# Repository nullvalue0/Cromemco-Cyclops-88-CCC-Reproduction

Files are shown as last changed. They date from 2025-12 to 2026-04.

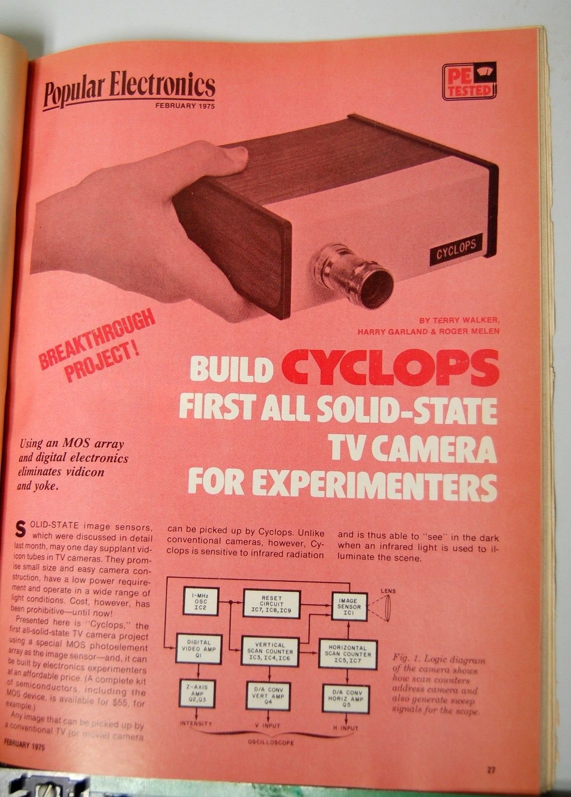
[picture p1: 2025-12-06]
Original Images/Popular Electronics Article 01.JPG

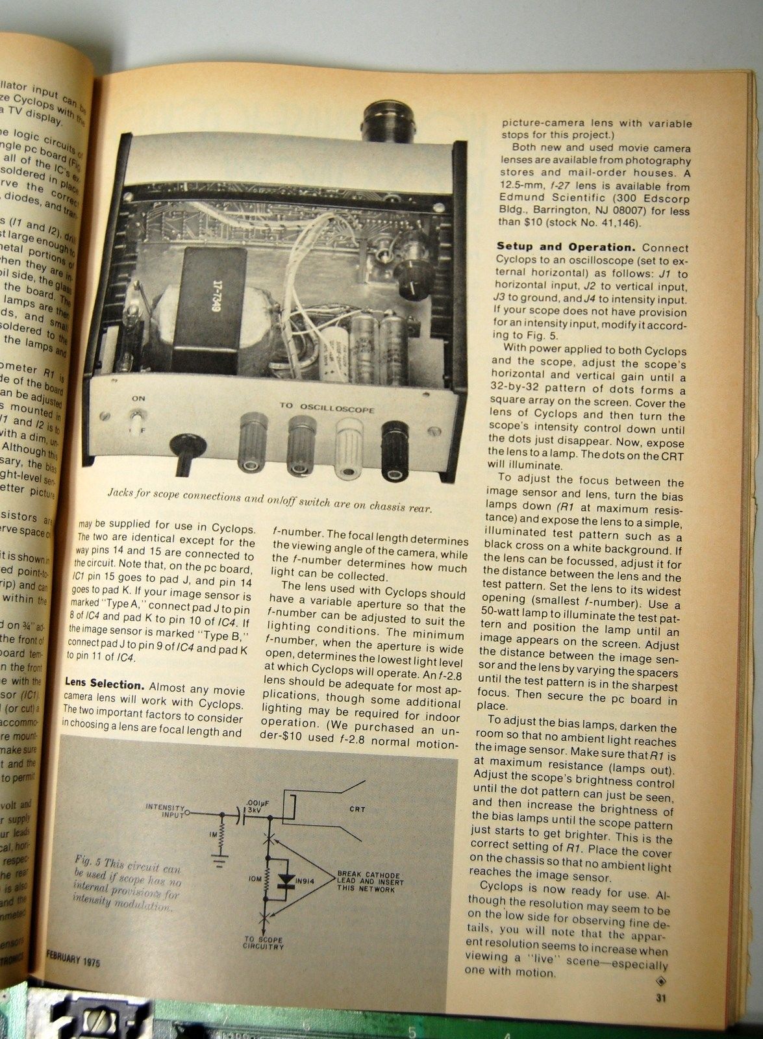
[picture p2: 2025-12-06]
Original Images/Popular Electronics Article 02.JPG

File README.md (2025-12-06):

This is an attempt to reproduce the PCB's for the Cromemco Cyclops digital camera, the 2-board set "88 CCC". The original digital cameras are basically impossible to find. Thankfully there has already been a [reproduction effort for the camera itself](http://wsudbrink.dyndns.org:8080/cyclops/index.html).

The next missing piece then would be the controller boards. While a few of the 88 CCC's have turned up, they are mainly already in collectors hands and still very rare. In several years of trying to find them I haven't been able to nab a set.

With the [Dazzler boards already successfully reproduced](https://forum.vcfed.org/index.php?threads/cromemco-dazzler-replica-project.77906), this seems like a great next project. I'll update this readme as the project progresses.

The 'Original Images' folder contains pictures of the original board set that I've found on various sites.

The 'Original Schematics' folder contains the original manual & schematics for the 88 CCC. I've combined the 2-page schematic into a single image for each board, making it much easier to reference.

The PCB folder will contain the reproduction Kicad files & gerbers for both S-100 boards.

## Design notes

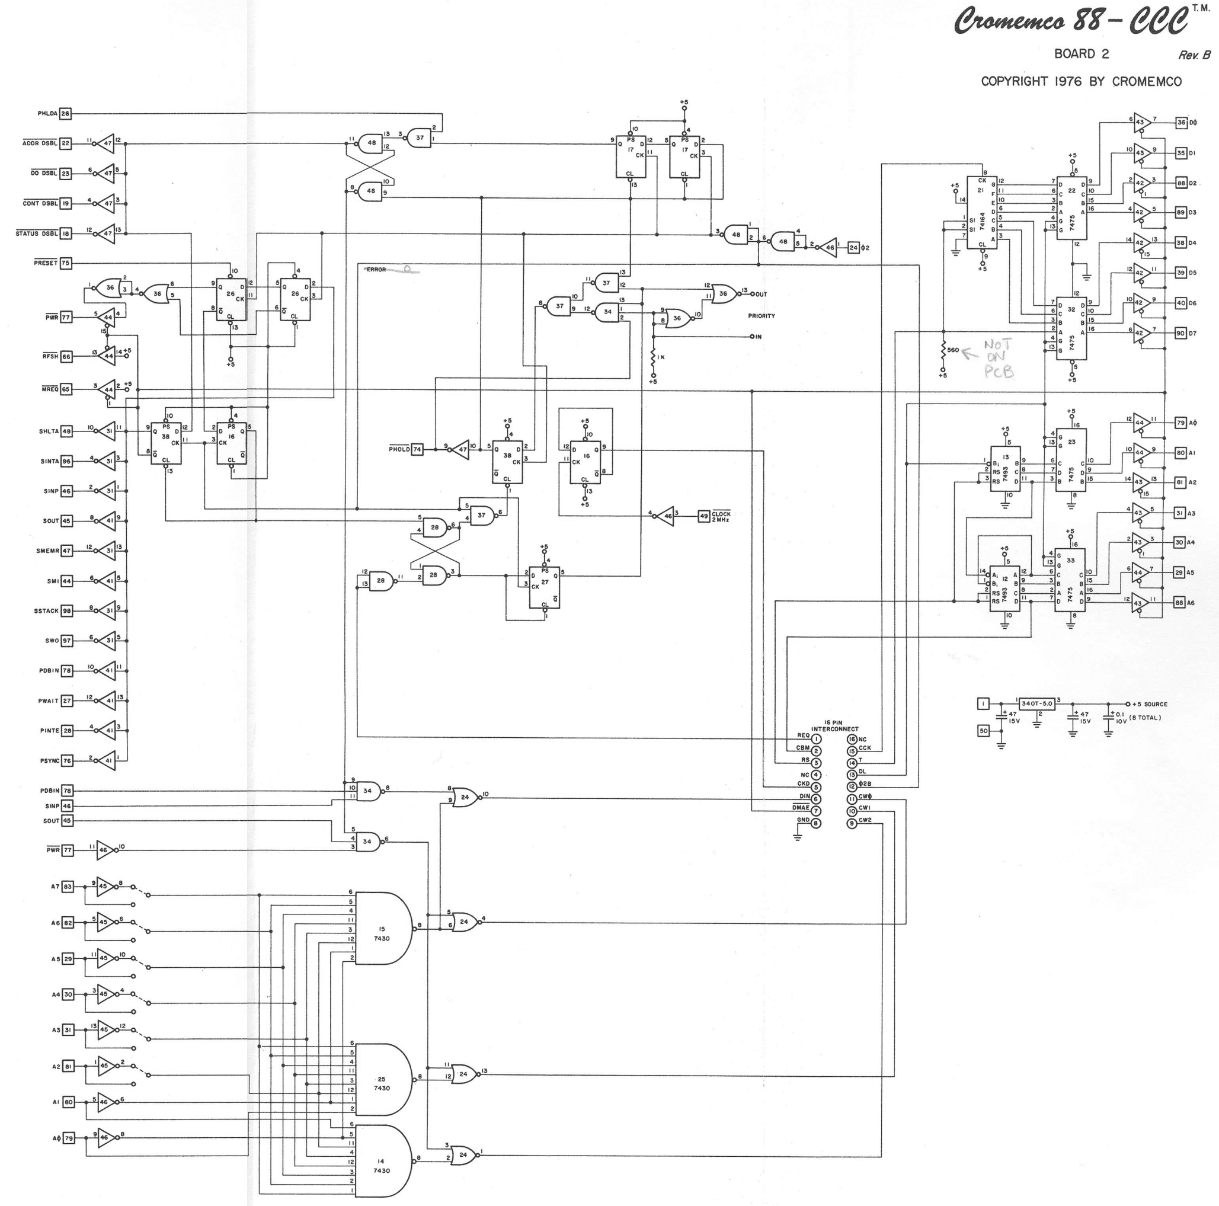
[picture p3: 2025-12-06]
Original Schematics/Cromemco_88-CCC_schematic-Board-2.png

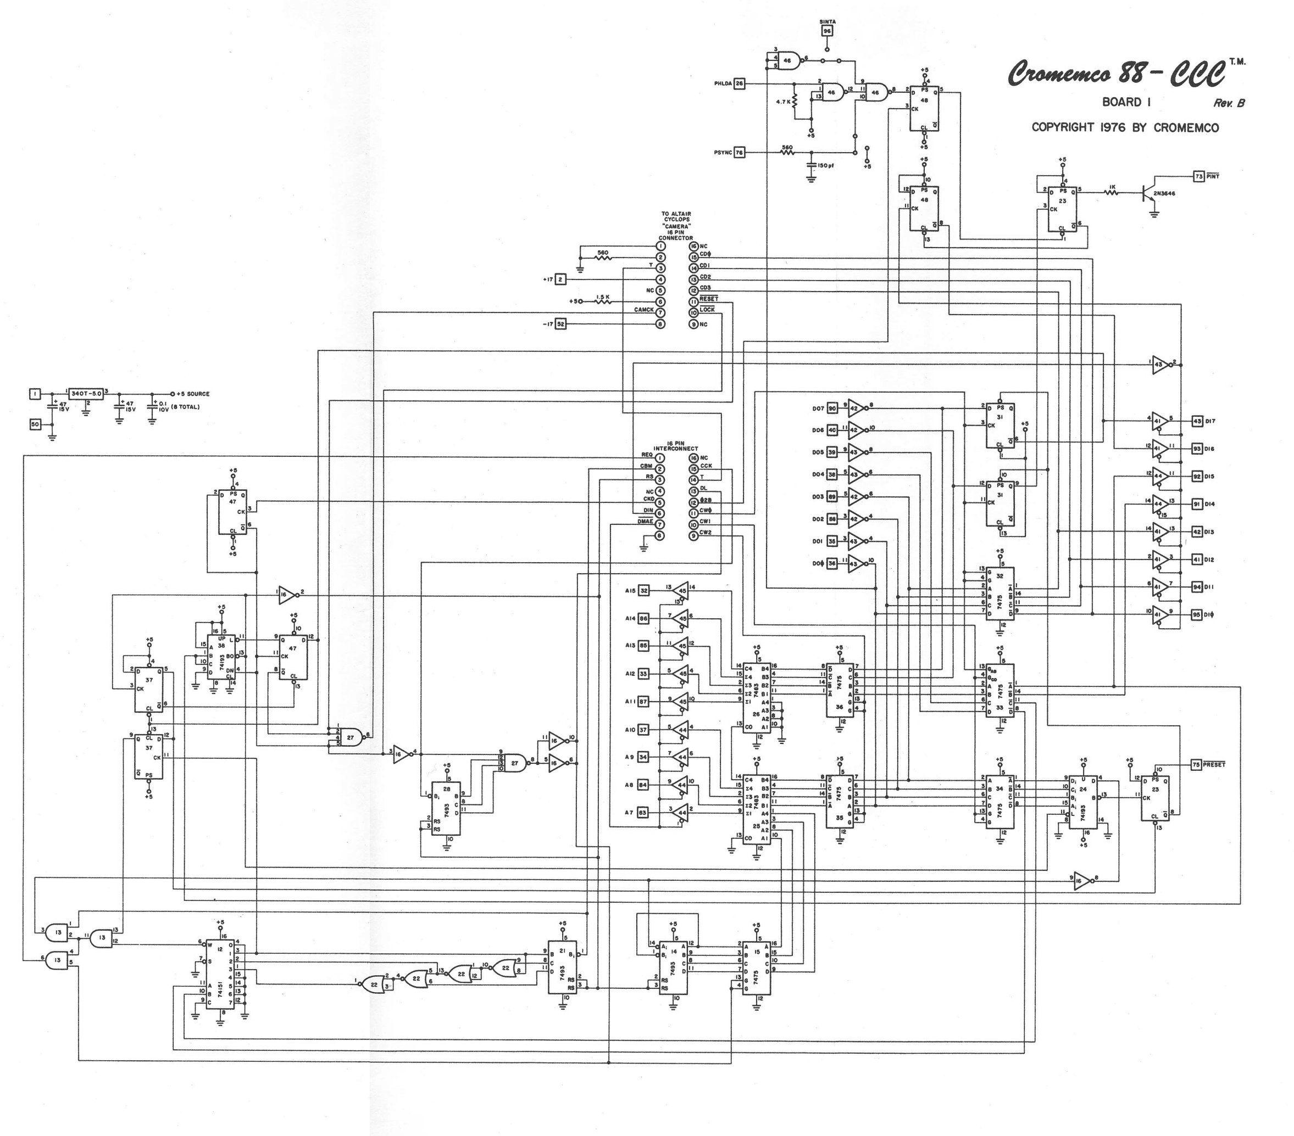
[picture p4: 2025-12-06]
Original Schematics/Cromemco_88-CCC_schematic-Board-1.png

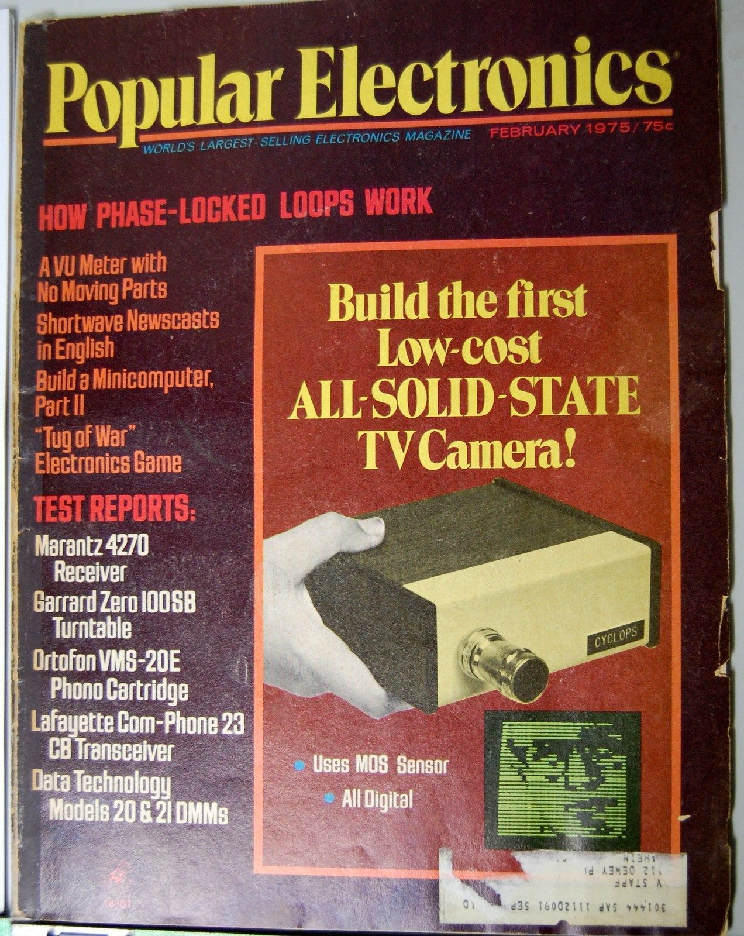
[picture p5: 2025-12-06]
Original Images/Popular Electronics cover.JPG

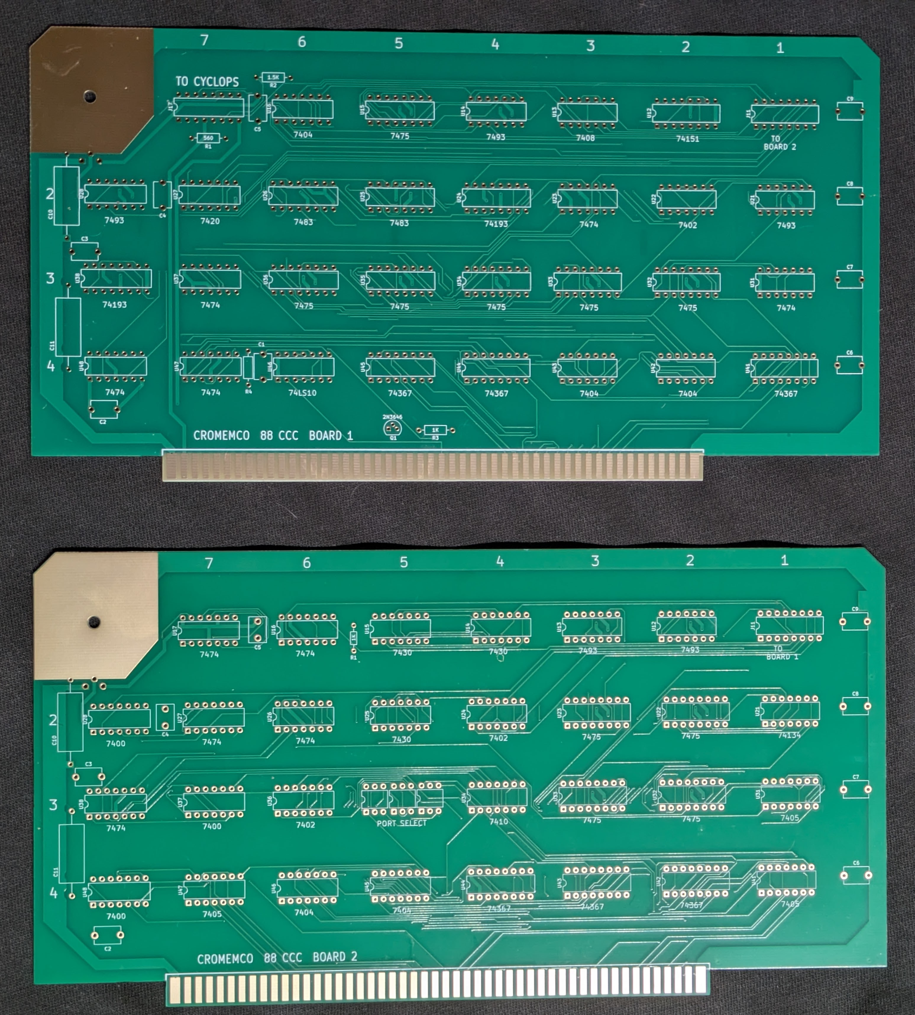
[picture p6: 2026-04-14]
88-CCC Reproduction PCBs.png

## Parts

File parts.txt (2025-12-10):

CYCLOPS - Board 1

X 11 - To Board 2 DIP 16
X 12 - 74151
X 13 - 7408
X 14 - 7493
X 15 - 7475
X 16 - 7404
X 17 - To Cyclops DIP 16
X 18 - LM7805
  
X 21 - 7493
X 22 - 7402
X 23 - 7474
X 24 - 74193
X 25 - 7483
X 26 - 7483
X 27 - 7420
X 28 - 7493
  
X 31 - 7474
X 32 - 7475
X 33 - 7475
X 34 - 7475
X 35 - 7475
X 36 - 7475
X 37 - 7474
X 38 - 74193
  
X 41 - 74367
X 42 - 7404
X 43 - 7404
X 44 - 74367
X 45 - 74367
X 46 - 74LS10
X 47 - 7474
X 48 - 7474

CYCLOPS - Board 2
  
X 11 - To Board 1 DIP 16
X 12 - 7493
X 13 - 7493
X 14 - 7430
X 15 - 7430
X 16 - 7474
X 17 - 7474
X 18 - LM7805
  
X 21 - 74164
X 22 - 7475
X 23 - 7475
X 24 - 7402
X 25 - 7430
X 26 - 7474
X 27 - 7474
X 28 - 7400
  
X 31 - 7405
X 32 - 7475
X 33 - 7475
X 34 - 7410
X 35 - Port Select
X 36 - 7402
X 37 - 7400
X 38 - 7474
  
X 41 - 7405
X 42 - 74367
X 43 - 74367
X 44 - 74367
X 45 - 7404
X 46 - 7404
X 47 - 7405
X 48 - 7400

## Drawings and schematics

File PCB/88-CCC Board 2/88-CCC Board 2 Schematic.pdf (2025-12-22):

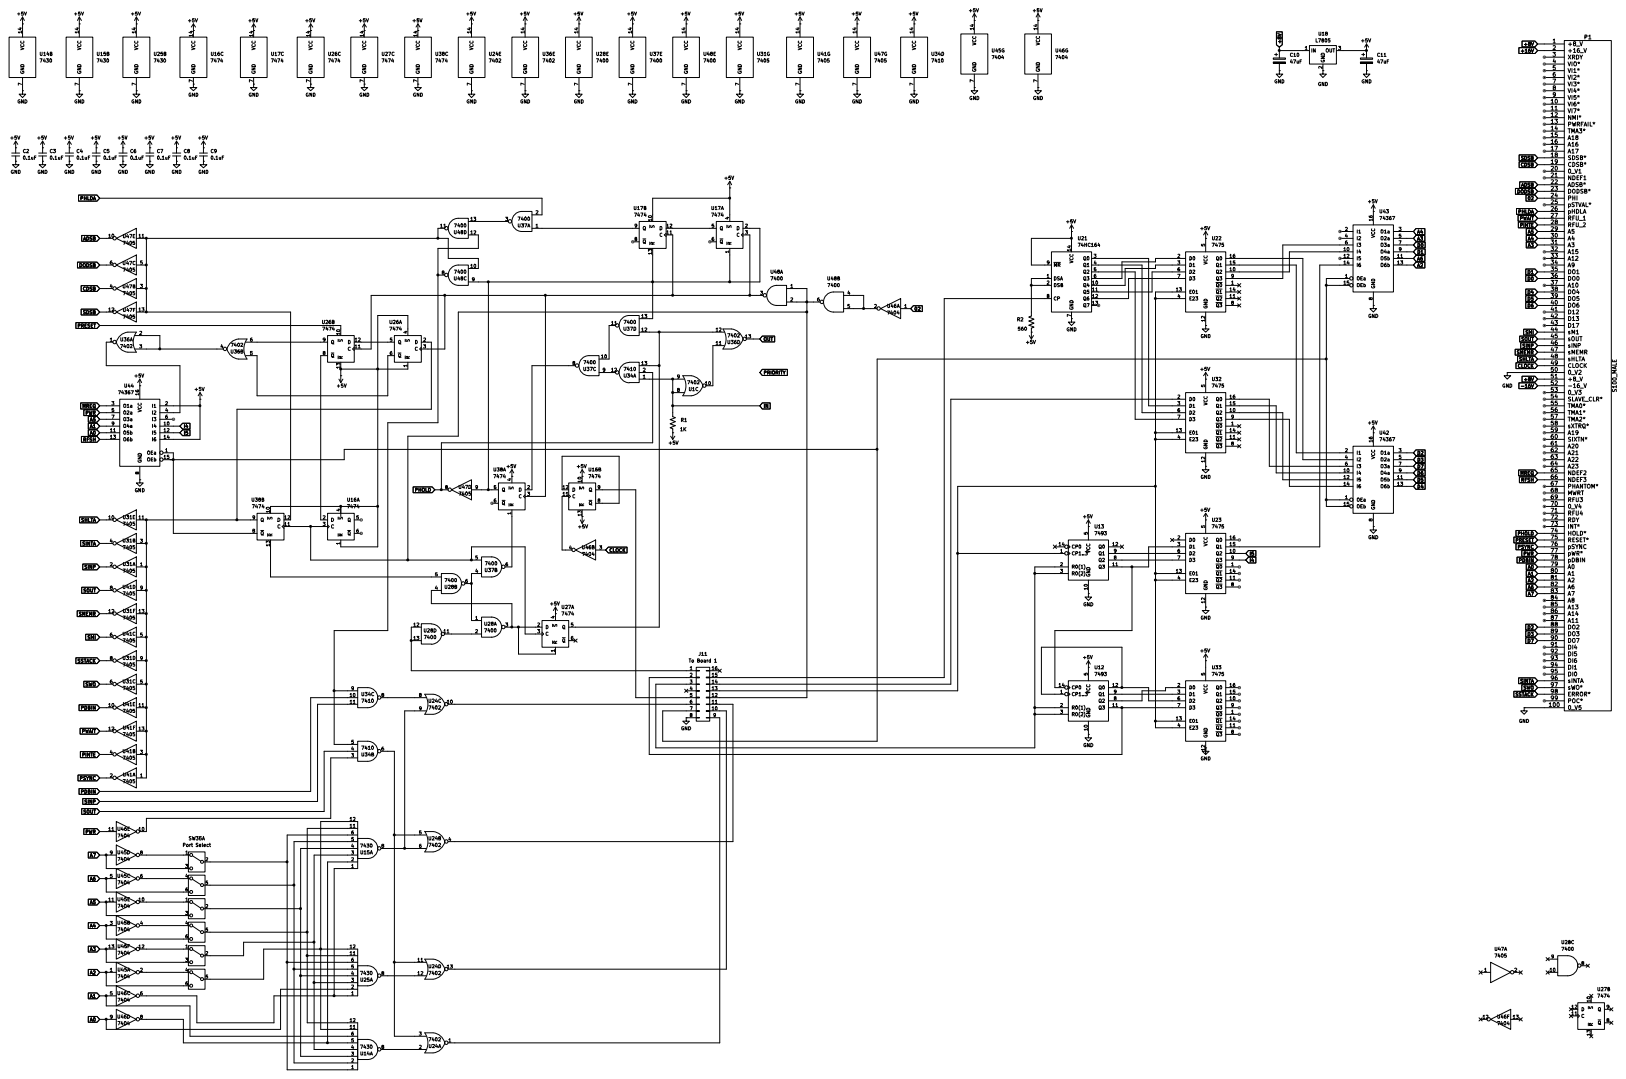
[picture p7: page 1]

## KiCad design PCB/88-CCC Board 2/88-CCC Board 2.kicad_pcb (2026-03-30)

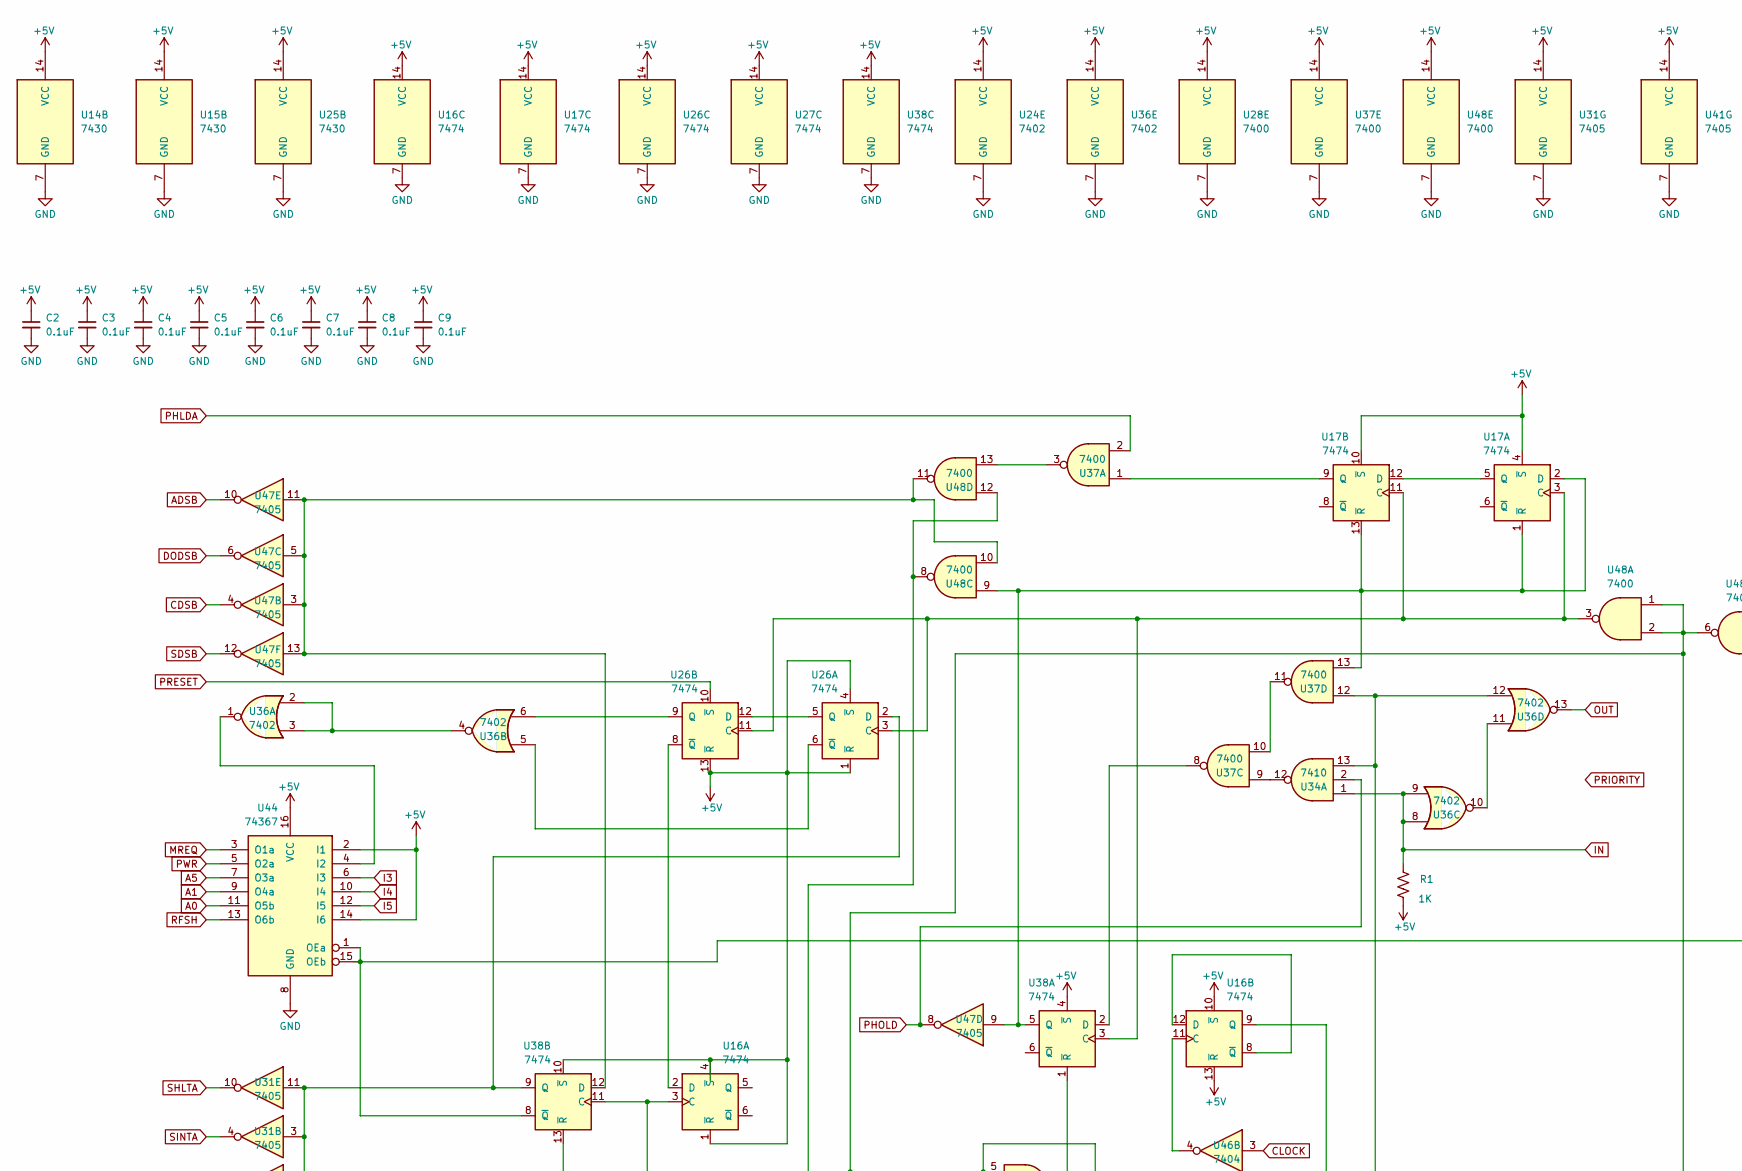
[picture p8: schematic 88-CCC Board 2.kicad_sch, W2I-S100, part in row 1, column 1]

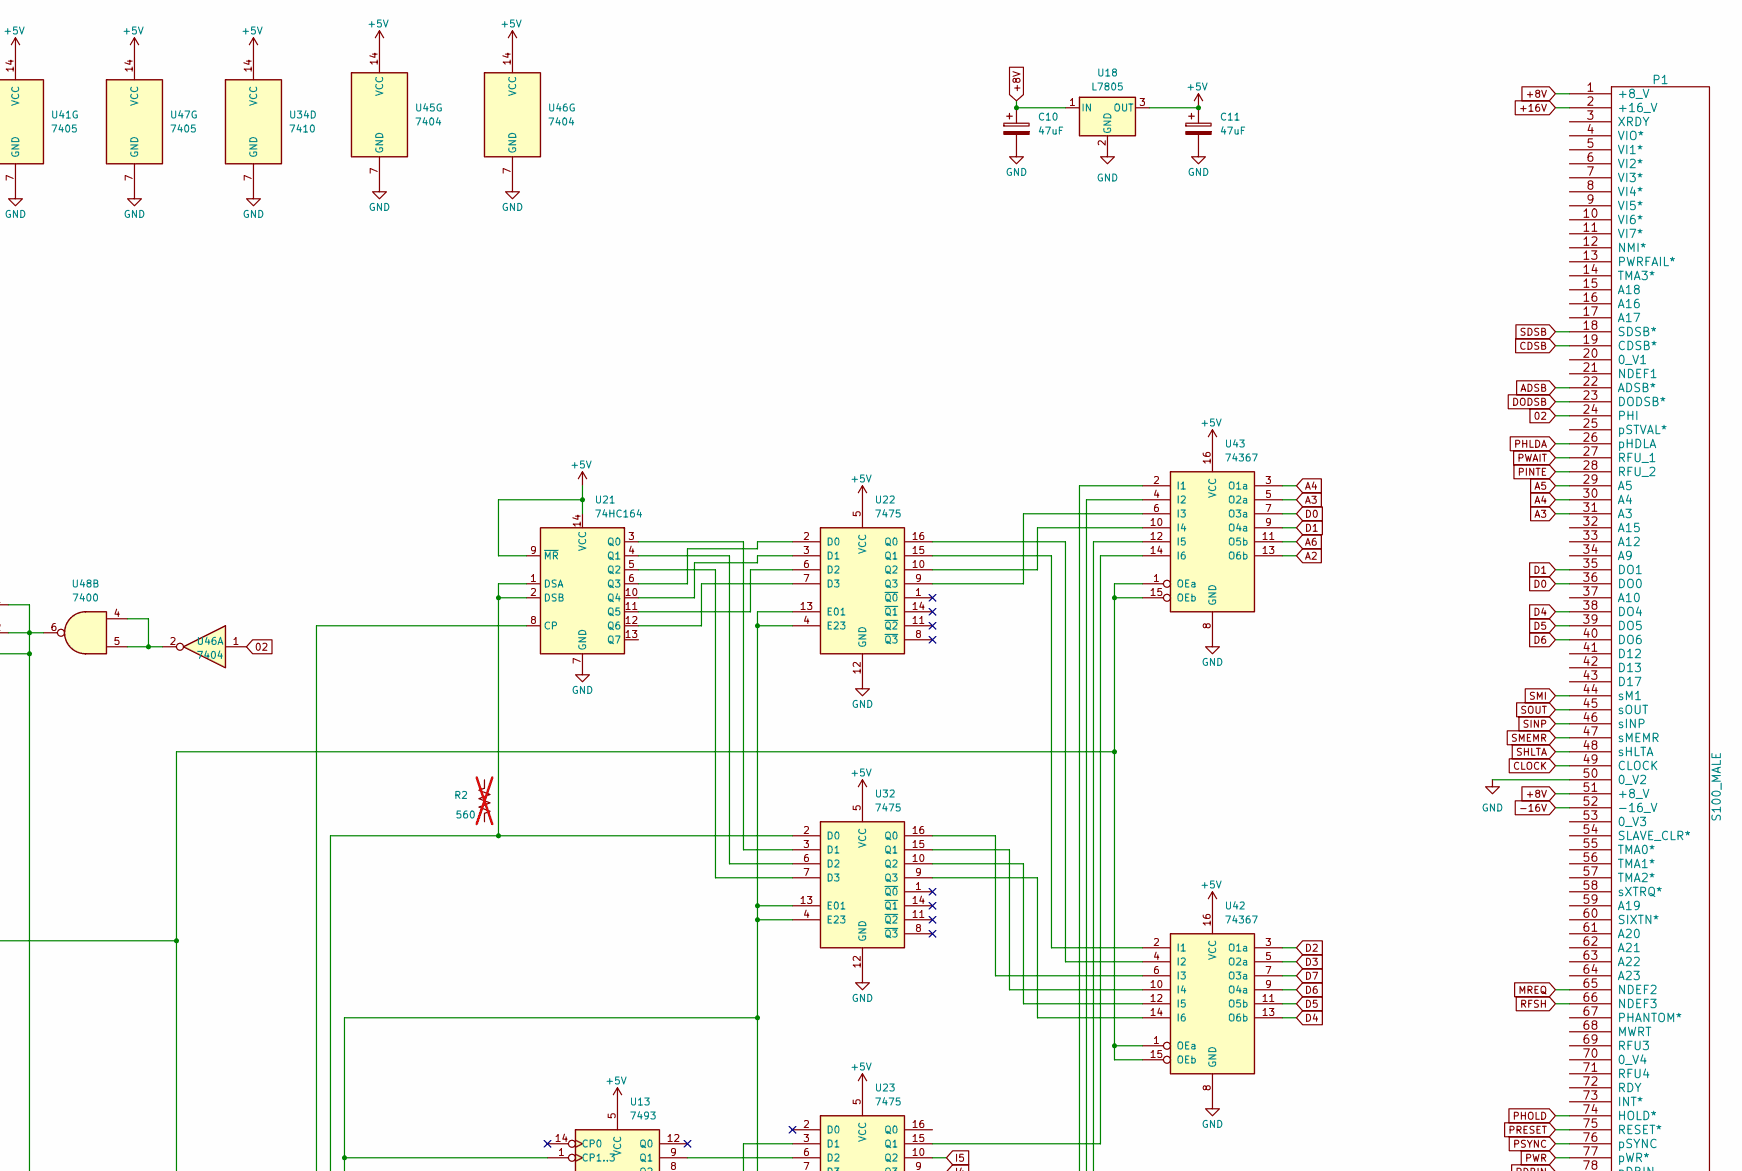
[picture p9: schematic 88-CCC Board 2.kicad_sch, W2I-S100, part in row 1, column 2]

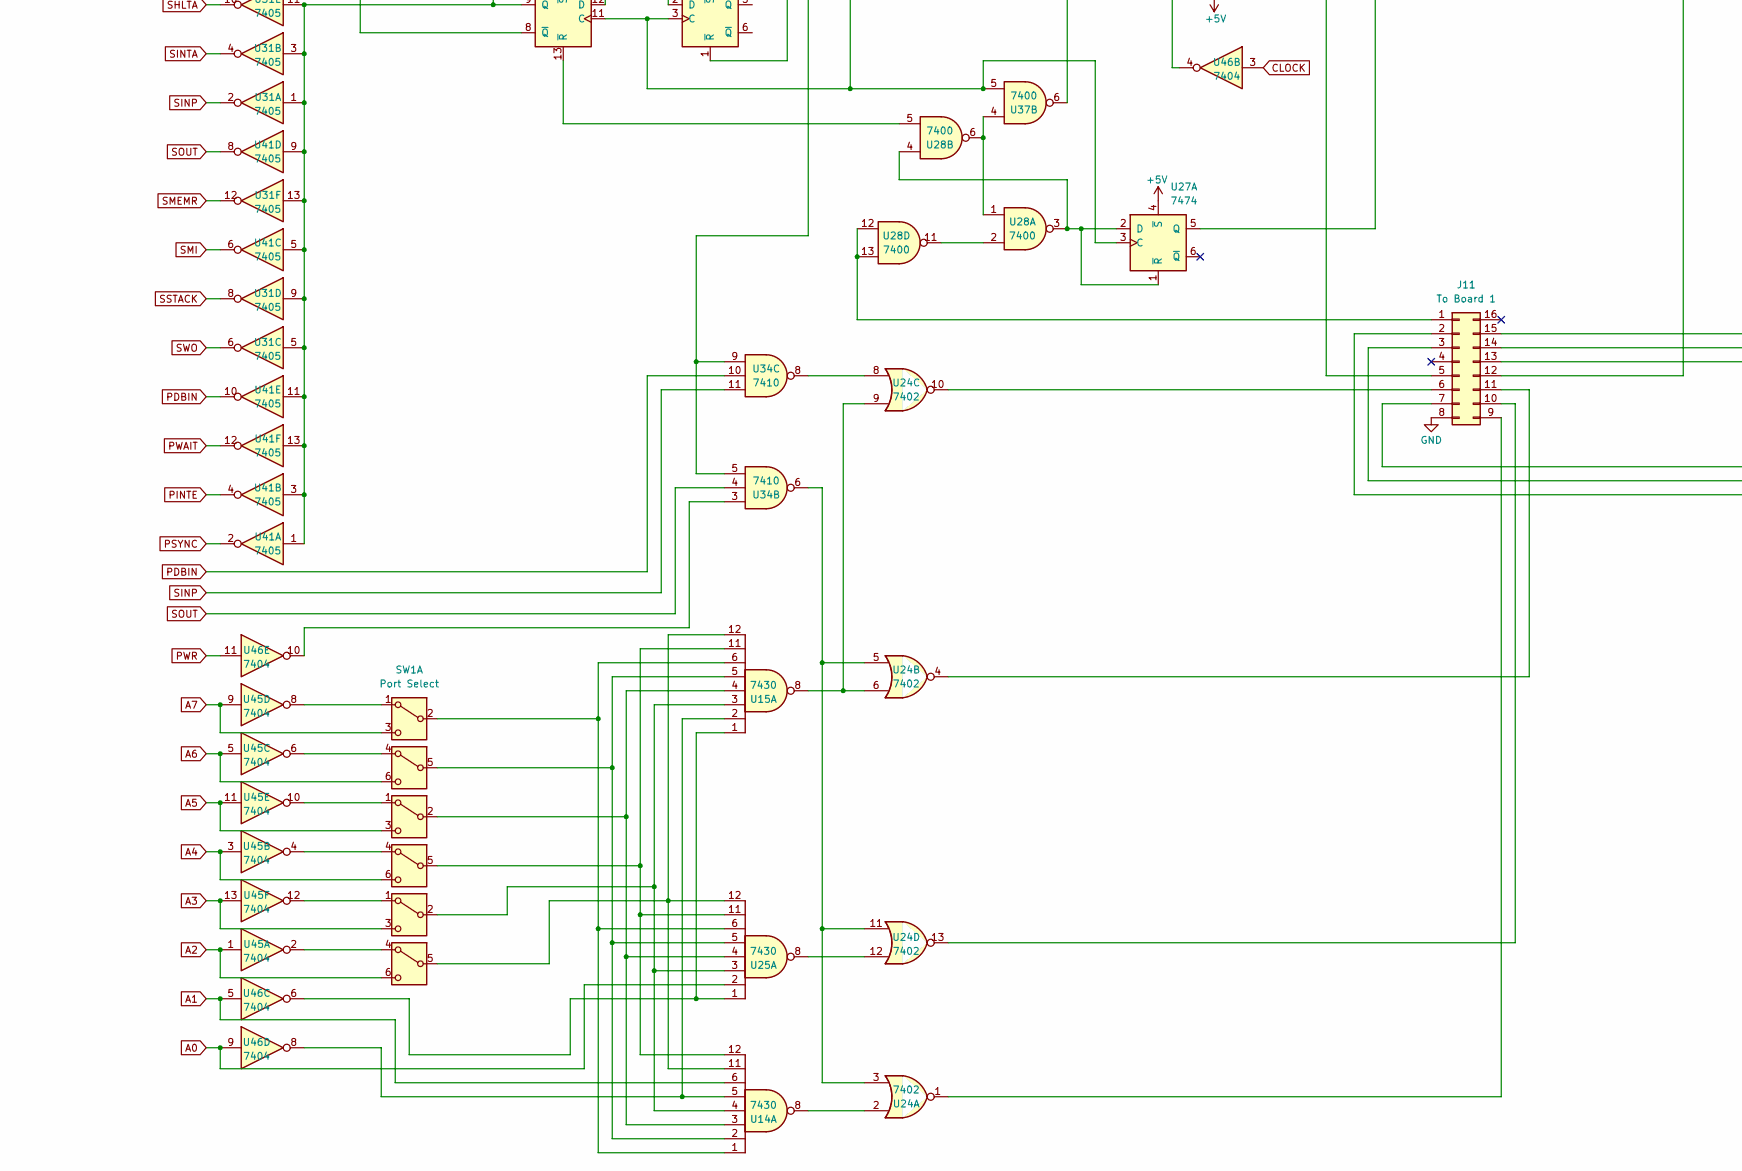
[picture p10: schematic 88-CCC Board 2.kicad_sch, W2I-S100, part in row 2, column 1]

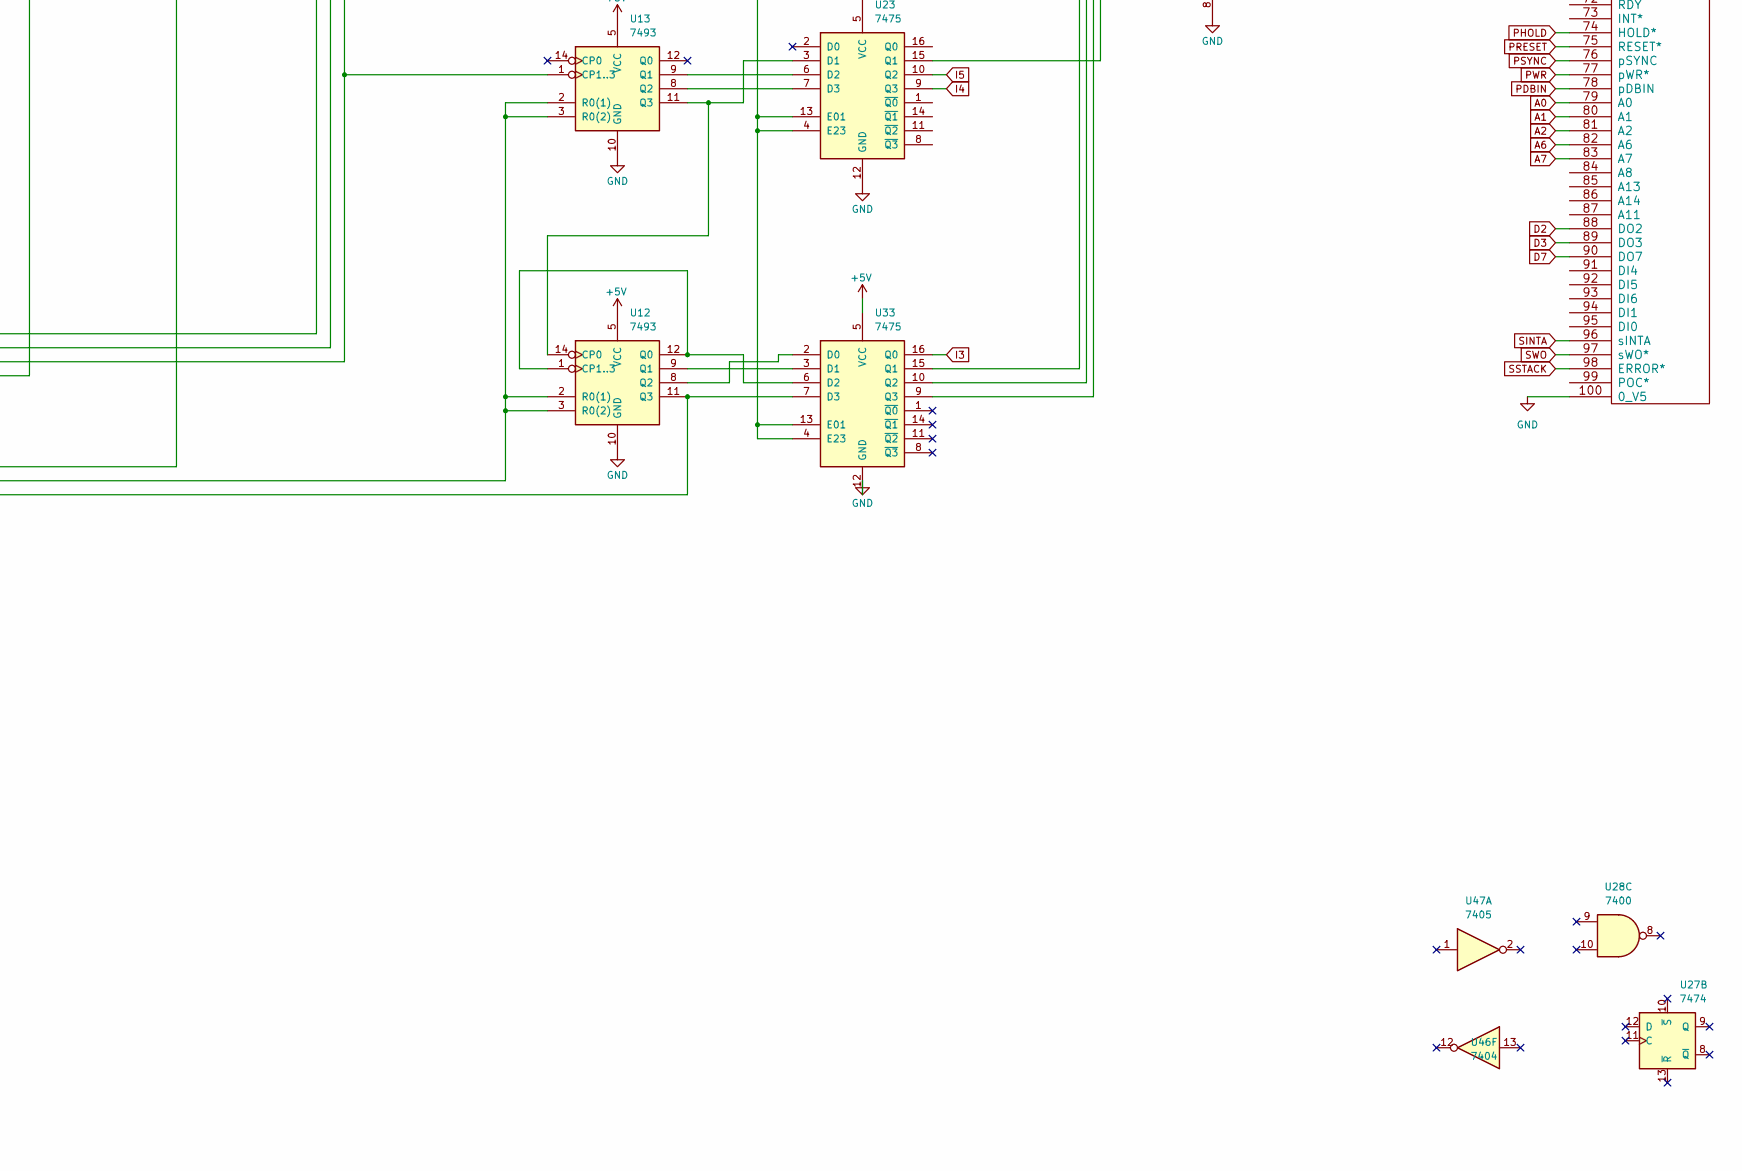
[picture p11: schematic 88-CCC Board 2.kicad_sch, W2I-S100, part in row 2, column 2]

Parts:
C2, C3, C4, C5, C6, C7, C8, C9: 0.1uF; C_Disc_D7.5mm_W5.0mm_P5.00mm
C10, C11: 47uF; C_Axial_L12.0mm_D9.5mm_P20.00mm_Horizontal
J11: To Board 1; DIP-16_W7.62mm
P1: S100_MALE
R1: 1K; R_Axial_DIN0204_L3.6mm_D1.6mm_P7.62mm_Horizontal; LCSC Part C1469
R2: 560; R_Axial_DIN0204_L3.6mm_D1.6mm_P7.62mm_Horizontal; LCSC Part C1469; not fitted
SW1: Port Select; DIP-6_W7.62mm
SW2, SW3: SW_DPDT_x2; DIP-6_W7.62mm
U12, U13: 7493; DIP-14_W7.62mm
U14, U15, U25: 7430; DIP-14_W7.62mm
U16, U17, U26, U27, U38: 7474; DIP-14_W7.62mm
U18: L7805; TO-220-3_Horizontal_TabDown
U21: 74HC164; DIP-14_W7.62mm
U22, U23, U32, U33: 7475; DIP-16_W7.62mm
U24, U36: 7402; DIP-14_W7.62mm
U28, U37, U48: 7400; DIP-14_W7.62mm
U31, U41, U47: 7405; DIP-14_W7.62mm
U34: 7410; DIP-14_W7.62mm
U42, U43, U44: 74367; DIP-16_W7.62mm
U45, U46: 7404; DIP-14_W7.62mm

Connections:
02: P1.24 (PHI), U46.1
+5V: C2.1, C3.1, C4.1, C5.1, C6.1, C7.1, C8.1, C9.1, C11.1, R1.1, U12.5 (VCC), U13.5 (VCC), U14.14 (VCC), U15.14 (VCC), U16.1 (~R), U16.4 (~S), U16.10 (~S), U16.13 (~R), U16.14 (VCC), U17.4 (~S), U17.10 (~S), U17.14 (VCC), U18.3 (OUT), U21.9 (~MR), U21.14 (VCC), U22.5 (VCC), U23.5 (VCC), U24.14 (VCC), U25.14 (VCC), U26.1 (~R), U26.4 (~S), U26.13 (~R), U26.14 (VCC), U27.4 (~S), U27.14 (VCC), U28.14 (VCC), U31.14 (VCC), U32.5 (VCC), U33.5 (VCC), U34.14 (VCC), U36.14 (VCC), U37.14 (VCC), U38.4 (~S), U38.10 (~S), U38.14 (VCC), U41.14 (VCC), U42.16 (VCC), U43.16 (VCC), U44.2 (I1), U44.14 (I6), U44.16 (VCC), U45.14 (VCC), U46.14 (VCC), U47.14 (VCC), U48.14 (VCC)
+8V: C10.1, P1.1 (+8_V), P1.51 (+8_V), U18.1 (IN)
+16V: P1.2 (+16_V)
-16V: P1.52 (-16_V)
A0: P1.79 (A0), U25.2, U44.11 (O5b), U46.9
A1: P1.80 (A1), U14.6, U44.9 (O4a), U46.5
A2: P1.81 (A2), SW3.6 (C), U43.13 (O6b), U45.1
A3: P1.31 (A3), SW3.3 (C), U43.5 (O2a), U45.13
A4: P1.30 (A4), SW2.6 (C), U43.3 (O1a), U45.3
A5: P1.29 (A5), SW2.3 (C), U44.7 (O3a), U45.11
A6: P1.82 (A6), SW1.6 (C), U43.11 (O5b), U45.5
A7: P1.83 (A7), SW1.3 (C), U45.9
ADSB: P1.22 (ADSB*), U47.10
CDSB: P1.19 (CDSB*), U47.4
CLOCK: P1.49 (CLOCK), U46.3
D0: P1.36 (DO0), U43.7 (O3a)
D1: P1.35 (DO1), U43.9 (O4a)
D2: P1.88 (DO2), U42.3 (O1a)
D3: P1.89 (DO3), U42.5 (O2a)
D4: P1.38 (DO4), U42.13 (O6b)
D5: P1.39 (DO5), U42.11 (O5b)
D6: P1.40 (DO6), U42.9 (O4a)
D7: P1.90 (DO7), U42.7 (O3a)
DODSB: P1.23 (DODSB*), U47.6
GND: C2.2, C3.2, C4.2, C5.2, C6.2, C7.2, C8.2, C9.2, C10.2, C11.2, J11.8, P1.50 (0_V2), P1.100 (0_V5), U12.10 (GND), U13.10 (GND), U14.7 (GND), U15.7 (GND), U16.7 (GND), U17.7 (GND), U18.2 (GND), U21.7 (GND), U22.12 (GND), U23.12 (GND), U24.7 (GND), U25.7 (GND), U26.7 (GND), U27.7 (GND), U28.7 (GND), U31.7 (GND), U32.12 (GND), U33.12 (GND), U34.7 (GND), U36.7 (GND), U37.7 (GND), U38.7 (GND), U41.7 (GND), U42.8 (GND), U43.8 (GND), U44.8 (GND), U45.7 (GND), U46.7 (GND), U47.7 (GND), U48.7 (GND)
I3: U33.16 (Q0), U44.6 (I3)
I4: U23.9 (Q3), U44.10 (I4)
I5: U23.10 (Q2), U44.12 (I5)
IN: R1.2, U34.1, U36.8, U36.9
MREQ: P1.65 (NDEF2), U44.3 (O1a)
unnamed: J11.1, U28.12, U28.13
unnamed: J11.2, U12.11 (Q3), U33.7 (D3)
unnamed: J11.3, U12.2 (R0(1)), U12.3 (R0(2)), U13.2 (R0(1)), U13.3 (R0(2))
unnamed: J11.5, U16.9 (Q)
unnamed: J11.6, U24.10
unnamed: J11.7, U38.8 (~Q), U42.1 (OEa), U42.15 (OEb), U43.1 (OEa), U43.15 (OEb), U44.1 (OEa), U44.15 (OEb)
unnamed: J11.9, U24.1
unnamed: J11.10, U24.13
unnamed: J11.11, U24.4
unnamed: J11.12, U16.3 (C), U27.3 (C), U37.5, U38.11 (C), U48.1, U48.2, U48.6
unnamed: J11.13, U13.1 (CP1..3), U22.4 (E23), U22.13 (E01), U23.4 (E23), U23.13 (E01), U32.4 (E23), U32.13 (E01), U33.4 (E23), U33.13 (E01)
unnamed: J11.14, U21.1 (DSA), U21.2 (DSB), U32.2 (D0)
unnamed: J11.15, U21.8 (CP)
unnamed: SW1.1 (A), U45.8
unnamed: SW1.2 (B), U14.1, U15.6, U25.6
unnamed: SW1.4 (A), U45.6
unnamed: SW1.5 (B), U14.2, U15.5, U25.5
unnamed: SW2.1 (A), U45.10
unnamed: SW2.2 (B), U14.3, U15.4, U25.4
unnamed: SW2.4 (A), U45.4
unnamed: SW2.5 (B), U14.12, U15.11, U25.11
unnamed: SW3.1 (A), U45.12
unnamed: SW3.2 (B), U14.4, U15.3, U25.3
unnamed: SW3.4 (A), U45.2
unnamed: SW3.5 (B), U14.11, U15.12, U25.12
unnamed: U12.14 (CP0), U13.11 (Q3), U23.3 (D1)
unnamed: U12.1 (CP1..3), U12.12 (Q0), U33.6 (D2)
unnamed: U12.9 (Q1), U33.3 (D1)
unnamed: U12.8 (Q2), U33.2 (D0)
unnamed: U13.9 (Q1), U23.6 (D2)
unnamed: U13.8 (Q2), U23.7 (D3)
unnamed: U14.5, U15.2, U46.8
unnamed: U14.8, U24.2
unnamed: U15.1, U25.1, U46.6
unnamed: U15.8, U24.6, U24.9
unnamed: U16.2 (D), U26.8 (~Q)
unnamed: U16.11 (C), U46.4
unnamed: U16.8 (~Q), U16.12 (D)
unnamed: U17.3 (C), U17.11 (C), U26.3 (C), U26.11 (C), U38.3 (C), U48.3
unnamed: U17.1 (~R), U17.2 (D), U17.13 (~R), U37.13, U38.5 (Q), U47.9, U48.9
unnamed: U17.5 (Q), U17.12 (D)
unnamed: U17.9 (Q), U37.1
unnamed: U21.3 (Q0), U32.3 (D1)
unnamed: U21.4 (Q1), U32.6 (D2)
unnamed: U21.5 (Q2), U32.7 (D3)
unnamed: U21.6 (Q3), U22.2 (D0)
unnamed: U21.10 (Q4), U22.3 (D1)
unnamed: U21.11 (Q5), U22.6 (D2)
unnamed: U21.12 (Q6), U22.7 (D3)
unnamed: U22.16 (Q0), U42.4 (I2)
unnamed: U22.15 (Q1), U42.2 (I1)
unnamed: U22.10 (Q2), U43.10 (I4)
unnamed: U22.9 (Q3), U43.6 (I3)
unnamed: U23.15 (Q1), U43.14 (I6)
unnamed: U24.8, U34.8
unnamed: U24.3, U24.5, U24.11, U34.6
unnamed: U24.12, U25.8
unnamed: U26.2 (D), U31.1, U31.3, U31.5, U31.9, U31.11, U31.13, U38.9 (Q), U41.1, U41.3, U41.5, U41.9, U41.11, U41.13
unnamed: U26.5 (Q), U26.12 (D)
unnamed: U26.6 (~Q), U36.5
unnamed: U26.9 (Q), U36.6
unnamed: U27.1 (~R), U27.2 (D), U28.3, U28.4
unnamed: U27.5 (Q), U34.13, U36.12, U37.12
unnamed: U28.1, U28.6, U37.4
unnamed: U28.2, U28.11
unnamed: U32.16 (Q0), U42.6 (I3)
unnamed: U32.15 (Q1), U42.10 (I4)
unnamed: U32.10 (Q2), U42.12 (I5)
unnamed: U32.9 (Q3), U42.14 (I6)
unnamed: U33.15 (Q1), U43.2 (I1)
unnamed: U33.10 (Q2), U43.4 (I2)
unnamed: U33.9 (Q3), U43.12 (I5)
unnamed: U34.3, U46.10
unnamed: U34.5, U34.9, U48.8, U48.12
unnamed: U34.12, U37.9
unnamed: U36.2, U36.3, U36.4
unnamed: U36.10, U36.11
unnamed: U37.3, U48.13
unnamed: U37.10, U37.11
unnamed: U37.8, U38.2 (D)
unnamed: U37.6, U38.1 (~R)
unnamed: U38.12 (D), U47.3, U47.5, U47.11, U47.13, U48.10, U48.11
unnamed: U28.5, U38.13 (~R)
unnamed: U36.1, U44.4 (I2)
unnamed: U46.2, U48.4, U48.5
OUT: U36.13
PDBIN: P1.78 (pDBIN), U34.10, U41.10
PHLDA: P1.26 (pHDLA), U37.2
PHOLD: P1.74 (HOLD*), U34.2, U47.8
PINTE: P1.28 (RFU_2), U41.4
PRESET: P1.75 (RESET*), U26.10 (~S)
PSYNC: P1.76 (pSYNC), U41.2
PWAIT: P1.27 (RFU_1), U41.12
PWR: P1.77 (pWR*), U44.5 (O2a), U46.11
RFSH: P1.66 (NDEF3), U44.13 (O6b)
SDSB: P1.18 (SDSB*), U47.12
SHLTA: P1.48 (sHLTA), U31.10
SINP: P1.46 (sINP), U31.2, U34.11
SINTA: P1.96 (sINTA), U31.4
SMEMR: P1.47 (sMEMR), U31.12
SMI: P1.44 (sM1), U41.6
SOUT: P1.45 (sOUT), U34.4, U41.8
SSTACK: P1.98 (ERROR*), U31.8
SWO: P1.97 (sWO*), U31.6

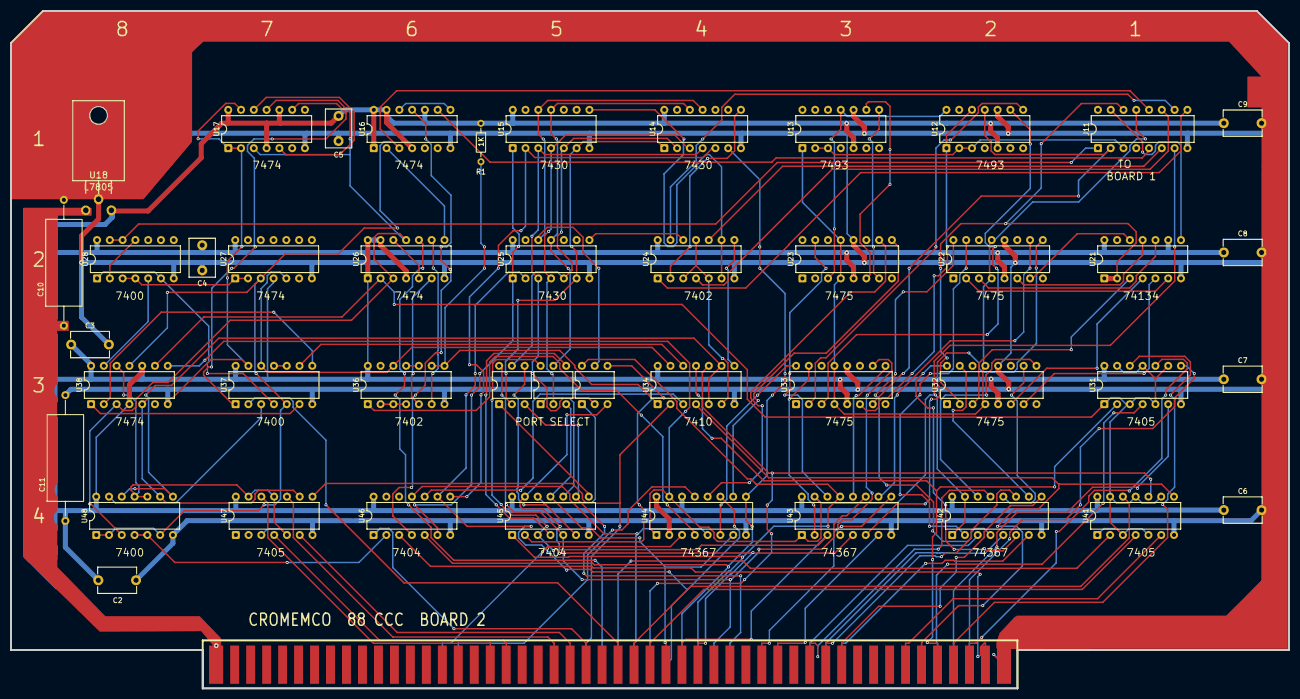
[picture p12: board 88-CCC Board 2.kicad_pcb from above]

Board: 2 copper layers, 254.0 x 134.6 mm, 46 parts (0 on the bottom side), 132 nets.

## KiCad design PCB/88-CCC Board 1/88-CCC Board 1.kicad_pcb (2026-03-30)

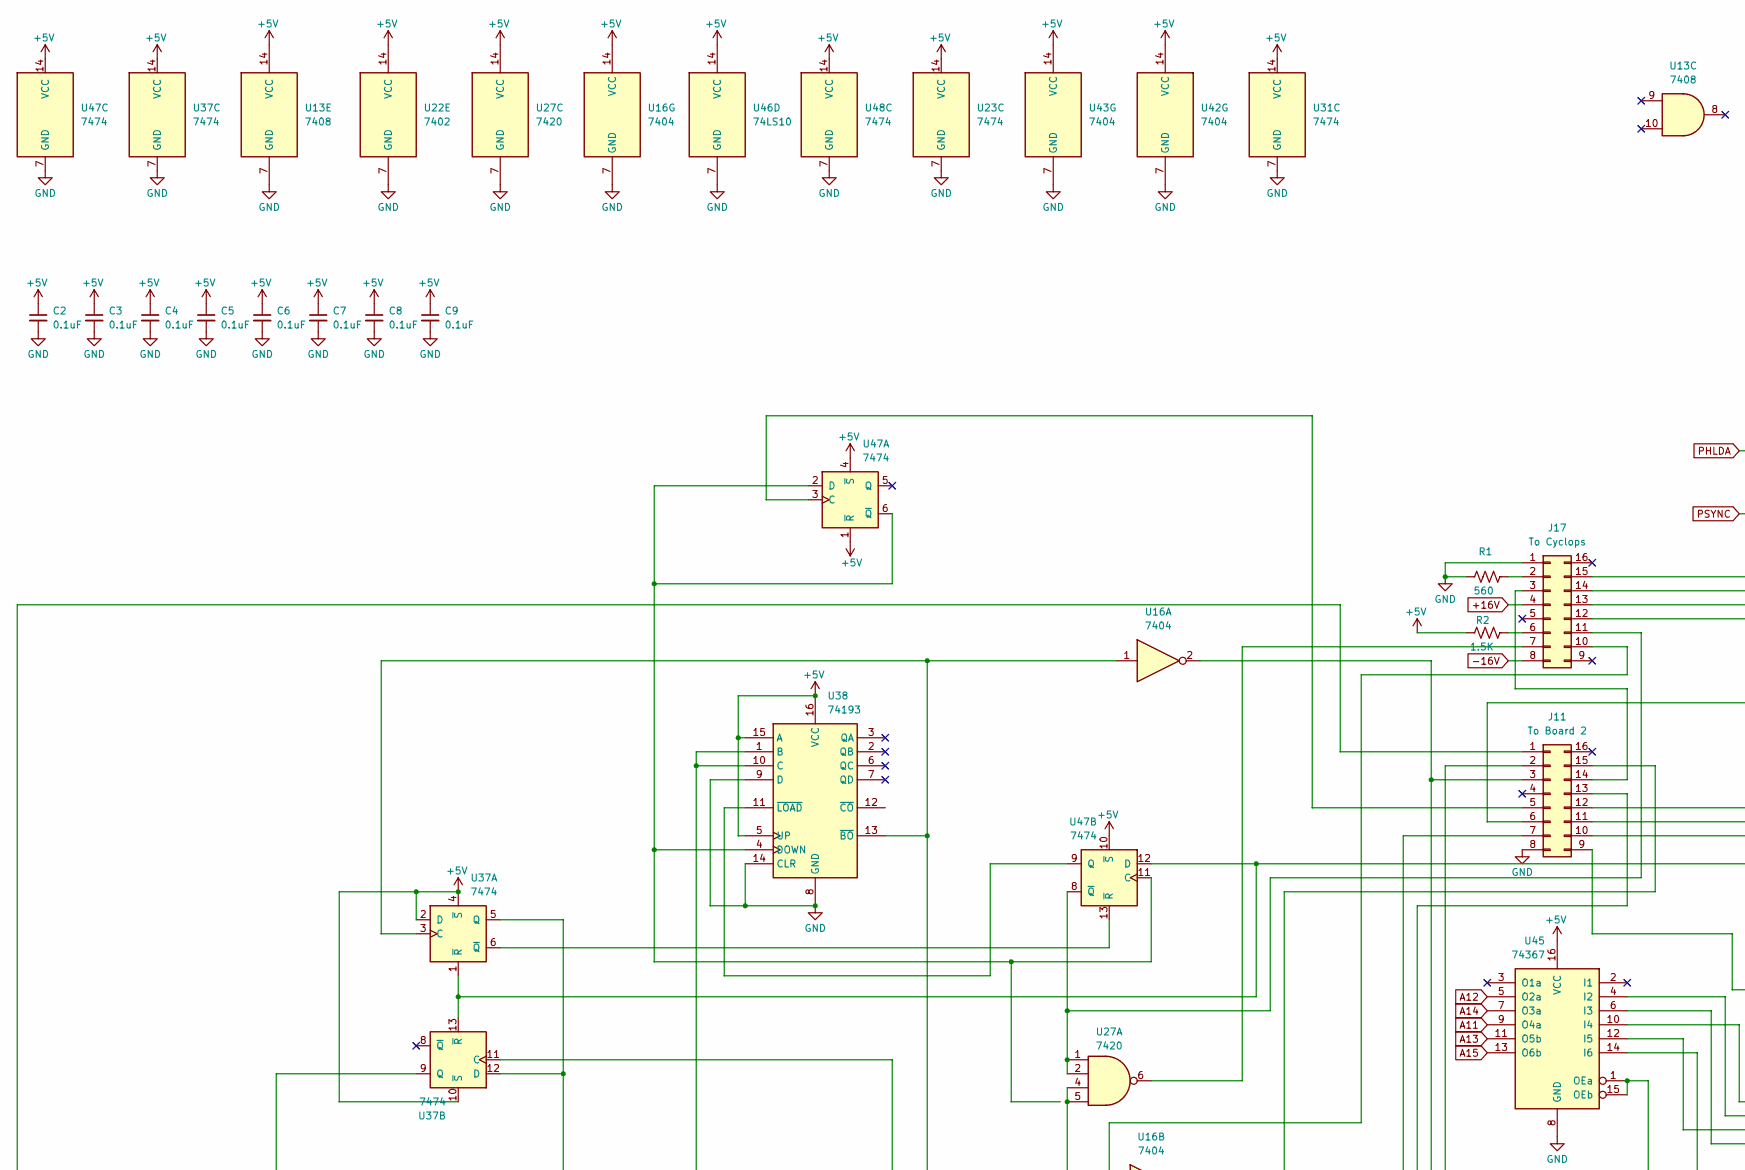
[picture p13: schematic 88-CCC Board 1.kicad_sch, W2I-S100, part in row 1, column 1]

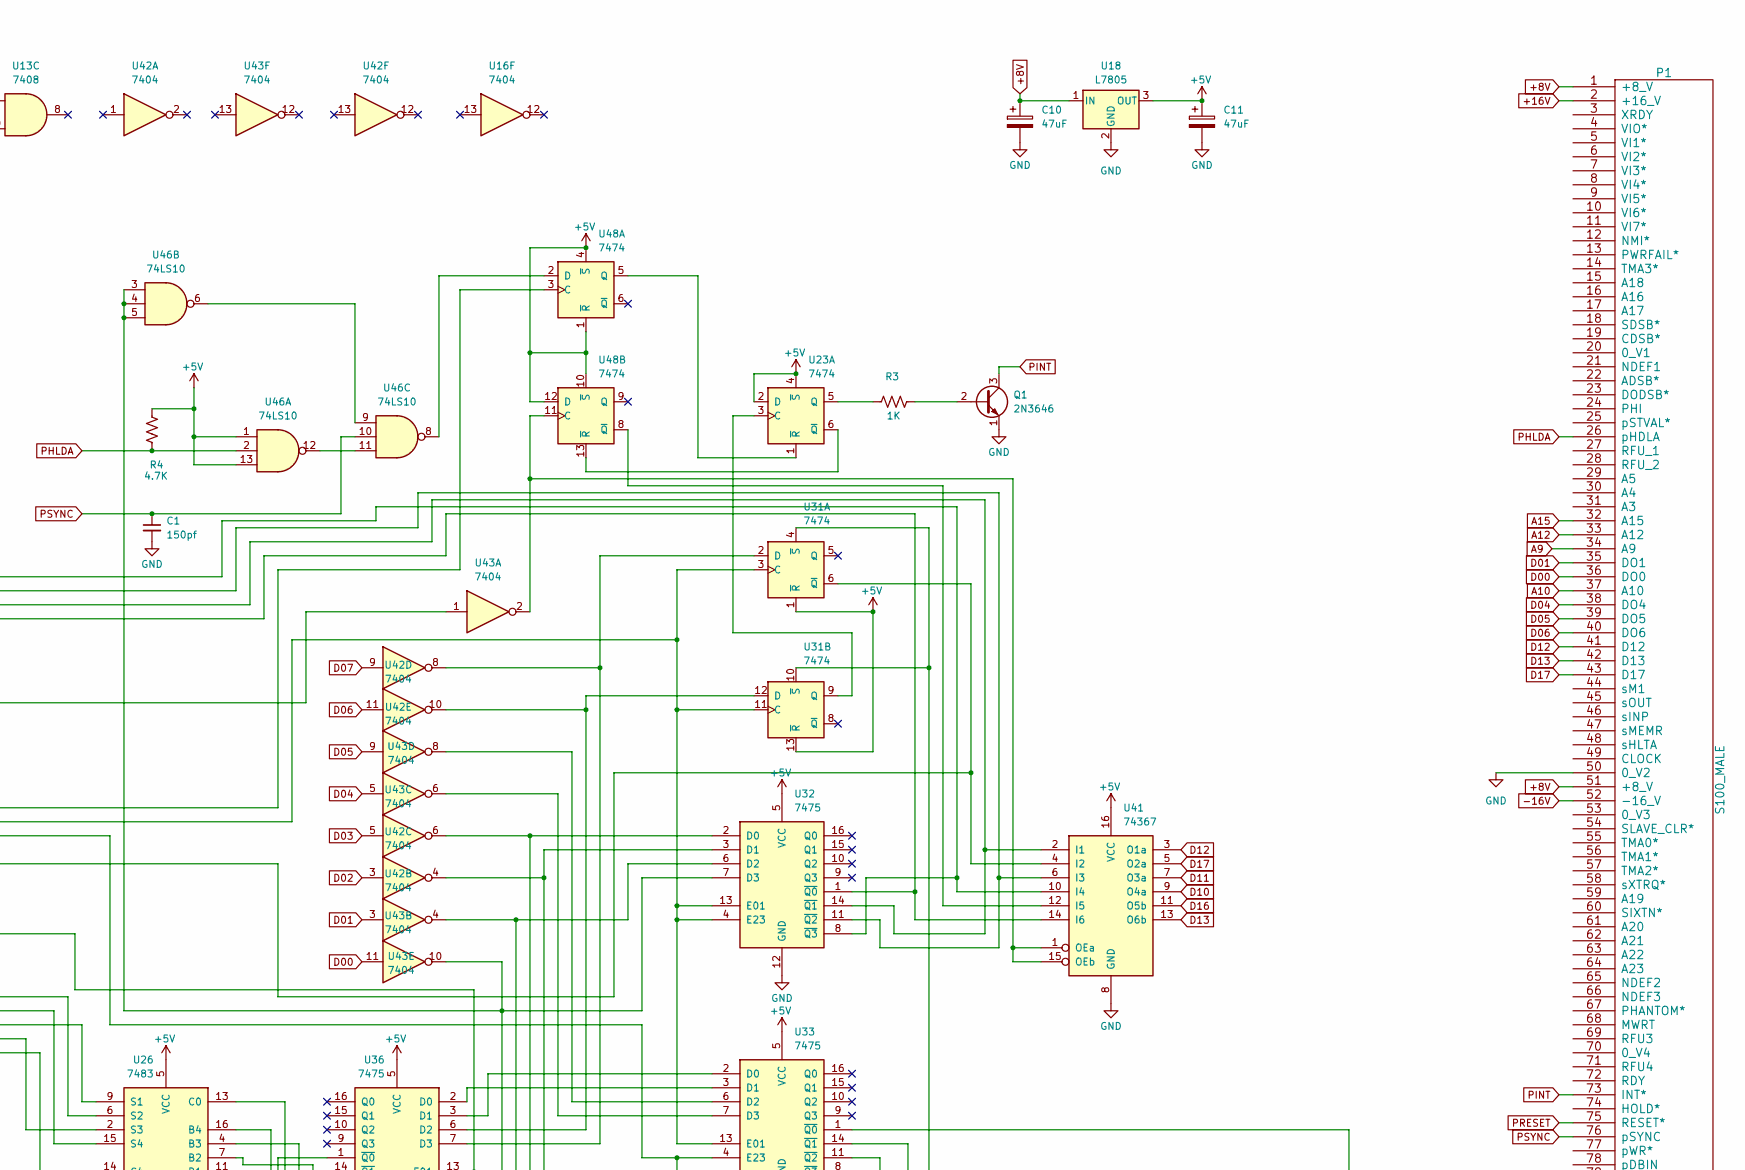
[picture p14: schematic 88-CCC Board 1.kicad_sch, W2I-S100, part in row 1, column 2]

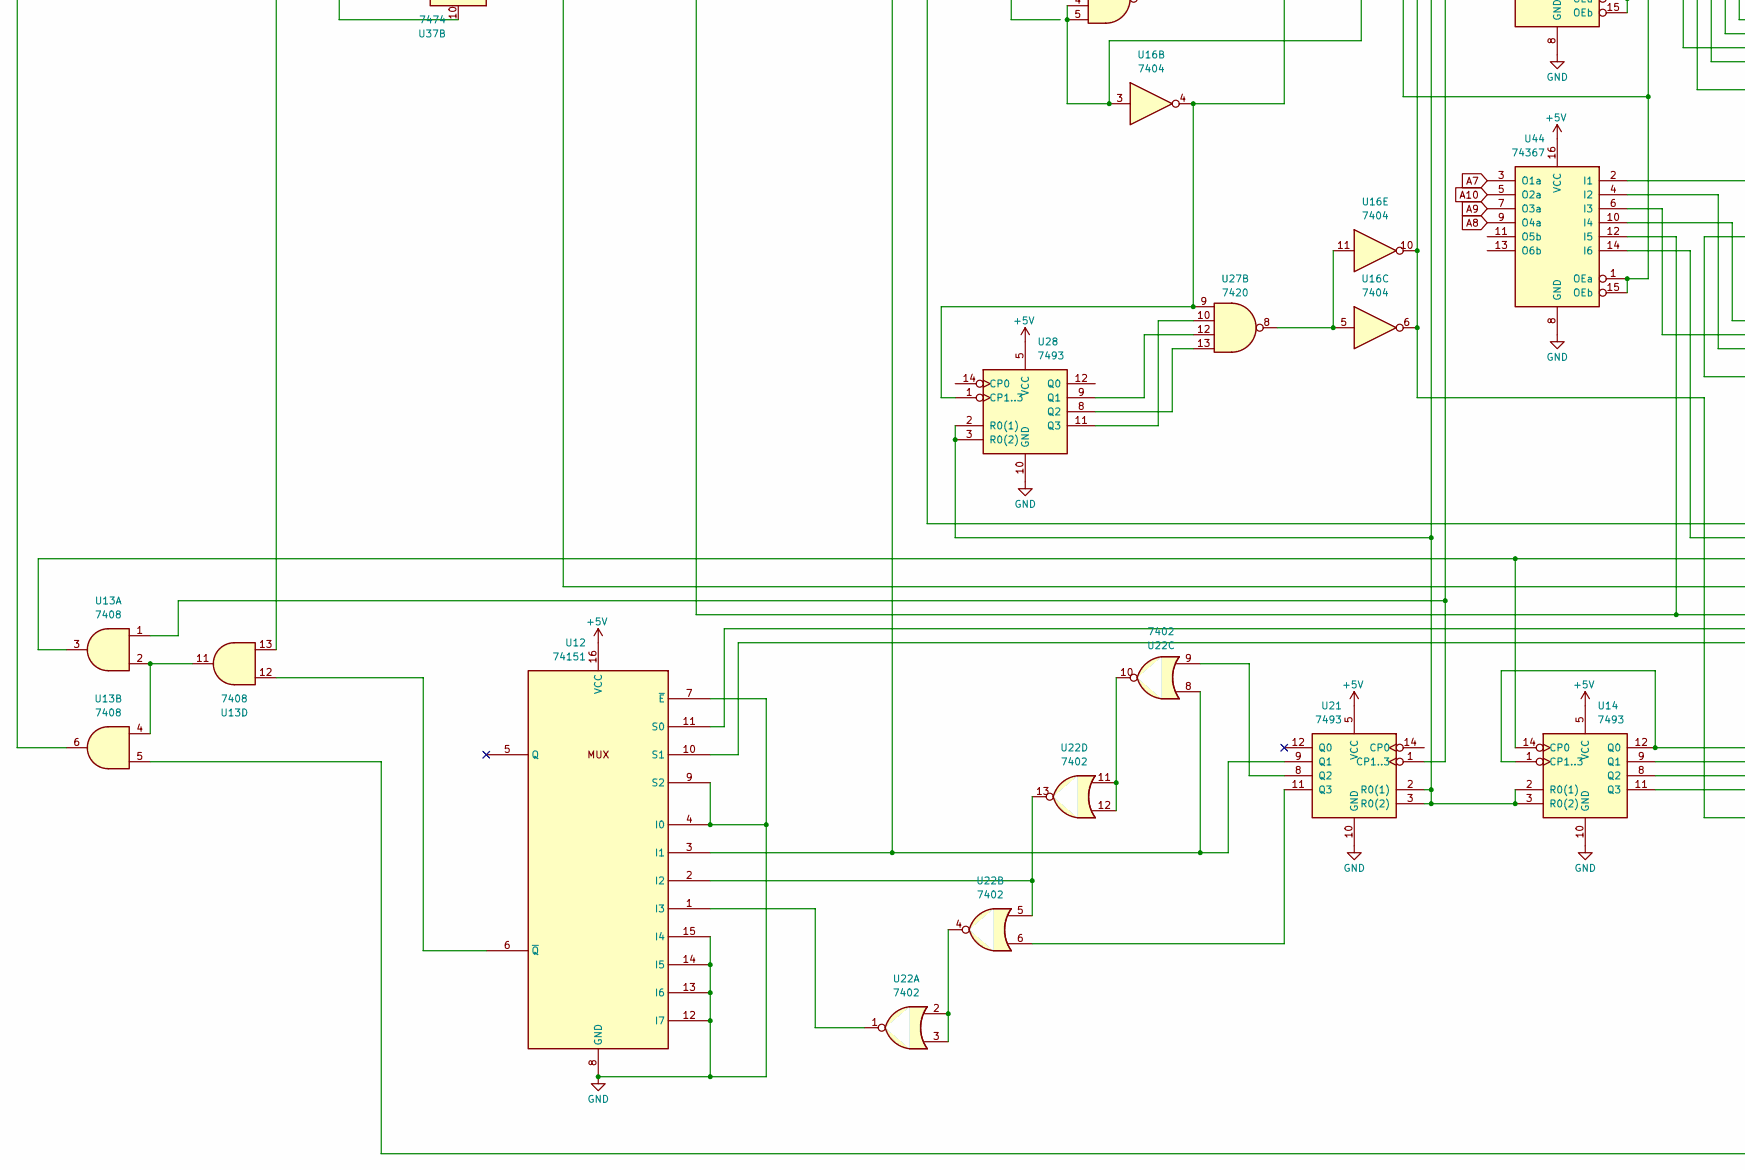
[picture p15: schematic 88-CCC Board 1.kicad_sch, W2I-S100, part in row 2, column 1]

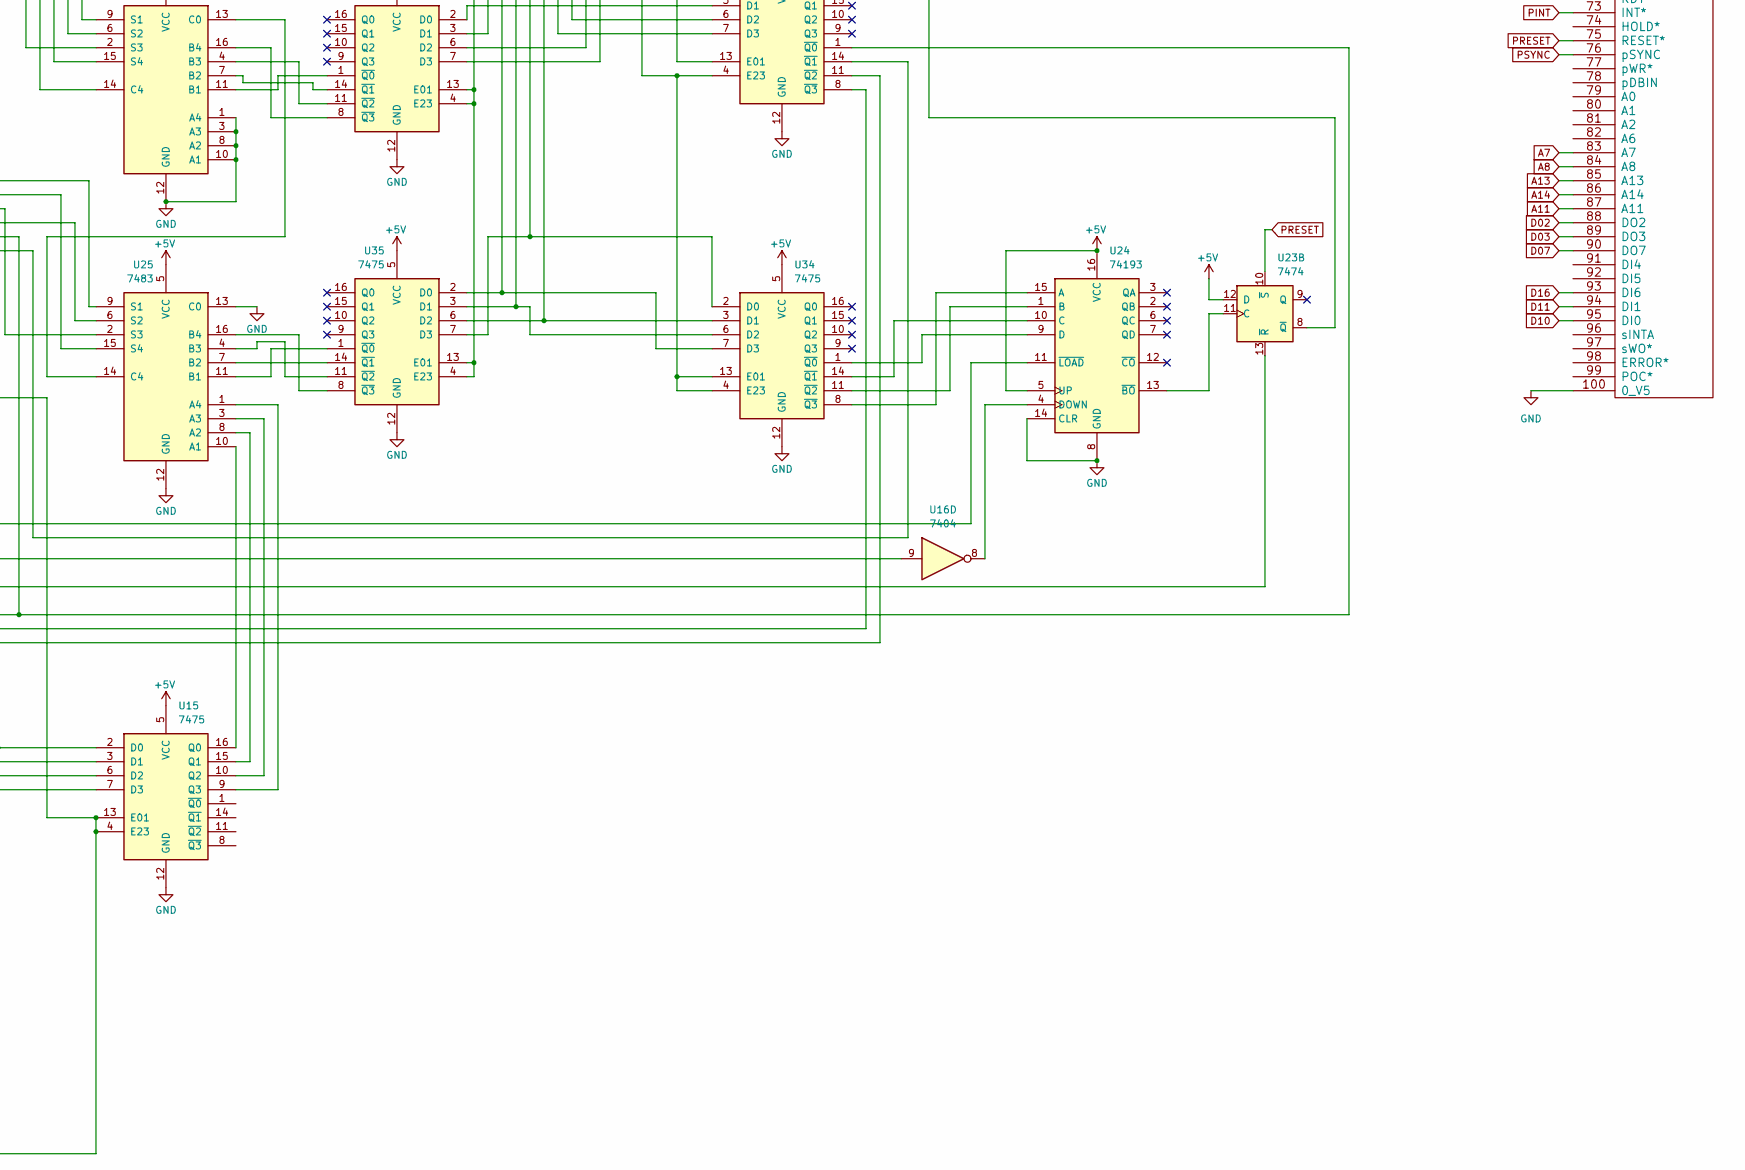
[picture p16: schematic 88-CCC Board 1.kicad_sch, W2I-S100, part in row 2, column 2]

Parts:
C1: 150pf; C_Disc_D7.5mm_W5.0mm_P7.50mm
C2, C3, C4, C5, C6, C7, C8, C9: 0.1uF; C_Disc_D7.5mm_W5.0mm_P7.50mm
C10, C11: 47uF; C_Axial_L17.0mm_D7.0mm_P25.00mm_Horizontal
J11: To Board 2; DIP-16_W7.62mm
J17: To Cyclops; DIP-16_W7.62mm
P1: S100_MALE
Q1: 2N3646; TO-92
R1: 560; R_Axial_DIN0207_L6.3mm_D2.5mm_P10.16mm_Horizontal
R2: 1.5K; R_Axial_DIN0207_L6.3mm_D2.5mm_P10.16mm_Horizontal
R3: 1K; R_Axial_DIN0207_L6.3mm_D2.5mm_P10.16mm_Horizontal
R4: 4.7K; R_Axial_DIN0207_L6.3mm_D2.5mm_P10.16mm_Horizontal
U12: 74151; DIP-16_W7.62mm
U13: 7408; DIP-14_W7.62mm
U14, U21, U28: 7493; DIP-14_W7.62mm
U15, U32, U33, U34, U35, U36: 7475; DIP-16_W7.62mm
U16, U42, U43: 7404; DIP-14_W7.62mm
U18: L7805; TO-220-3_Horizontal_TabDown
U22: 7402; DIP-14_W7.62mm
U23, U31, U37, U47, U48: 7474; DIP-14_W7.62mm
U24, U38: 74193; DIP-16_W7.62mm
U25, U26: 7483; DIP-16_W7.62mm
U27: 7420; DIP-14_W7.62mm
U41, U44, U45: 74367; DIP-16_W7.62mm
U46: 74LS10; DIP-14_W7.62mm

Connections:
+5V: C2.1, C3.1, C4.1, C5.1, C6.1, C7.1, C8.1, C9.1, C11.1, R2.1, R4.1, U12.16 (VCC), U13.14 (VCC), U14.5 (VCC), U15.5 (VCC), U16.14 (VCC), U18.3 (OUT), U21.5 (VCC), U22.14 (VCC), U23.2 (D), U23.4 (~S), U23.12 (D), U23.14 (VCC), U24.5 (UP), U24.16 (VCC), U25.5 (VCC), U26.5 (VCC), U27.14 (VCC), U28.5 (VCC), U31.1 (~R), U31.13 (~R), U31.14 (VCC), U32.5 (VCC), U33.5 (VCC), U34.5 (VCC), U35.5 (VCC), U36.5 (VCC), U37.2 (D), U37.4 (~S), U37.10 (~S), U37.14 (VCC), U38.5 (UP), U38.15 (A), U38.16 (VCC), U41.16 (VCC), U42.14 (VCC), U43.14 (VCC), U44.16 (VCC), U45.16 (VCC), U46.1, U46.13, U46.14 (VCC), U47.1 (~R), U47.4 (~S), U47.10 (~S), U47.14 (VCC), U48.1 (~R), U48.4 (~S), U48.10 (~S), U48.12 (D), U48.14 (VCC)
+8V: C10.1, P1.1 (+8_V), P1.51 (+8_V), U18.1 (IN)
+16V: J17.4, P1.2 (+16_V)
-16V: J17.8, P1.52 (-16_V)
A7: P1.83 (A7), U44.3 (O1a)
A8: P1.84 (A8), U44.9 (O4a)
A9: P1.34 (A9), U44.7 (O3a)
A10: P1.37 (A10), U44.5 (O2a)
A11: P1.87 (A11), U45.9 (O4a)
A12: P1.33 (A12), U45.5 (O2a)
A13: P1.85 (A13), U45.11 (O5b)
A14: P1.86 (A14), U45.7 (O3a)
A15: P1.32 (A15), U45.13 (O6b)
D00: P1.36 (DO0), U43.11
D01: P1.35 (DO1), U43.3
D02: P1.88 (DO2), U42.3
D03: P1.89 (DO3), U42.5
D04: P1.38 (DO4), U43.5
D05: P1.39 (DO5), U43.9
D06: P1.40 (DO6), U42.11
D07: P1.90 (DO7), U42.9
D10: P1.95 (DI0), U41.9 (O4a)
D11: P1.94 (DI1), U41.7 (O3a)
D12: P1.41 (D12), U41.3 (O1a)
D13: P1.42 (D13), U41.13 (O6b)
D16: P1.93 (DI6), U41.11 (O5b)
D17: P1.43 (D17), U41.5 (O2a)
GND: C1.2, C2.2, C3.2, C4.2, C5.2, C6.2, C7.2, C8.2, C9.2, C10.2, C11.2, J11.8, J17.1, P1.50 (0_V2), P1.100 (0_V5), Q1.1 (E), R1.1, U12.4 (I0), U12.7 (~E), U12.8 (GND), U12.9 (S2), U12.12 (I7), U12.13 (I6), U12.14 (I5), U12.15 (I4), U13.7 (GND), U14.10 (GND), U15.12 (GND), U16.7 (GND), U18.2 (GND), U21.10 (GND), U22.7 (GND), U23.7 (GND), U24.8 (GND), U24.14 (CLR), U25.12 (GND), U25.13 (C0), U26.1 (A4), U26.3 (A3), U26.8 (A2), U26.10 (A1), U26.12 (GND), U27.7 (GND), U28.10 (GND), U31.7 (GND), U32.12 (GND), U33.12 (GND), U34.12 (GND), U35.12 (GND), U36.12 (GND), U37.7 (GND), U38.8 (GND), U38.9 (D), U38.14 (CLR), U41.8 (GND), U42.7 (GND), U43.7 (GND), U44.8 (GND), U45.8 (GND), U46.7 (GND), U47.7 (GND), U48.7 (GND)
unnamed: J11.1, U13.6
unnamed: J11.2, U13.1, U21.1 (CP1..3)
unnamed: J11.3, U14.2 (R0(1)), U14.3 (R0(2)), U16.2, U21.2 (R0(1)), U21.3 (R0(2)), U28.2 (R0(1)), U28.3 (R0(2))
unnamed: J11.5, U47.3 (C)
unnamed: J11.6, U43.1
unnamed: J11.7, U44.1 (OEa), U44.15 (OEb), U45.1 (OEa), U45.15 (OEb)
unnamed: J11.9, U35.4 (E23), U35.13 (E01), U36.4 (E23), U36.13 (E01)
unnamed: J11.10, U33.4 (E23), U34.4 (E23), U34.13 (E01)
unnamed: J11.11, U31.3 (C), U31.11 (C), U32.4 (E23), U32.13 (E01), U33.13 (E01)
unnamed: J11.12, U48.3 (C)
unnamed: J11.13, U13.5, U15.4 (E23), U15.13 (E01), U16.6, U16.10
unnamed: J11.14, J17.3
unnamed: J11.15, U16.4, U27.9, U28.1 (CP1..3)
unnamed: J17.2, R1.2
unnamed: J17.6, R2.2
unnamed: J17.7, U27.6
unnamed: J17.10, U16.3, U27.4, U27.5
unnamed: J17.11, U27.1, U27.2, U47.8 (~Q)
unnamed: J17.12, U32.1 (~Q0), U41.14 (I6)
unnamed: J17.13, U32.14 (~Q1), U41.2 (I1)
unnamed: J17.14, U32.11 (~Q2), U41.6 (I3)
unnamed: J17.15, U32.8 (~Q3), U41.10 (I4)
unnamed: Q1.2 (B), R3.2
unnamed: U12.3 (I1), U21.9 (Q1), U22.8, U37.11 (C)
unnamed: U12.2 (I2), U22.5, U22.13
unnamed: U12.1 (I3), U22.1
unnamed: U12.11 (S0), U33.8 (~Q3)
unnamed: U12.10 (S1), U33.11 (~Q2)
unnamed: U12.6 (~Q), U13.12
unnamed: U13.2, U13.4, U13.11
unnamed: U13.3, U14.14 (CP0), U16.9
unnamed: U14.1 (CP1..3), U14.12 (Q0), U15.2 (D0)
unnamed: U14.9 (Q1), U15.3 (D1)
unnamed: U14.8 (Q2), U15.6 (D2)
unnamed: U14.11 (Q3), U15.7 (D3)
unnamed: U15.16 (Q0), U25.10 (A1)
unnamed: U15.15 (Q1), U25.8 (A2)
unnamed: U15.10 (Q2), U25.3 (A3)
unnamed: U15.9 (Q3), U25.1 (A4)
unnamed: U16.5, U16.11, U27.8
unnamed: U21.8 (Q2), U22.9
unnamed: U21.11 (Q3), U22.6
unnamed: U22.2, U22.3, U22.4
unnamed: U22.10, U22.11, U22.12
unnamed: U23.3 (C), U31.9 (Q)
unnamed: R3.1, U23.5 (Q)
unnamed: U23.6 (~Q), U48.13 (~R)
unnamed: U23.1 (~R), U48.5 (Q)
unnamed: U23.11 (C), U24.13 (~BO)
unnamed: U23.8 (~Q), U31.4 (~S), U31.10 (~S)
unnamed: U23.13 (~R), U37.5 (Q), U37.12 (D)
unnamed: U24.15 (A), U34.8 (~Q3)
unnamed: U24.1 (B), U34.11 (~Q2)
unnamed: U24.10 (C), U34.14 (~Q1)
unnamed: U24.9 (D), U34.1 (~Q0)
unnamed: U16.8, U24.4 (DOWN)
unnamed: U16.1, U24.11 (~LOAD), U37.3 (C), U38.13 (~BO)
unnamed: U25.11 (B1), U35.1 (~Q0)
unnamed: U25.7 (B2), U35.14 (~Q1)
unnamed: U25.4 (B3), U35.11 (~Q2)
unnamed: U25.16 (B4), U35.8 (~Q3)
unnamed: U25.14 (C4), U26.13 (C0)
unnamed: U25.9 (S1), U44.2 (I1)
unnamed: U25.6 (S2), U44.10 (I4)
unnamed: U25.2 (S3), U44.6 (I3)
unnamed: U25.15 (S4), U44.4 (I2)
unnamed: U26.11 (B1), U36.1 (~Q0)
unnamed: U26.7 (B2), U36.14 (~Q1)
unnamed: U26.4 (B3), U36.11 (~Q2)
unnamed: U26.16 (B4), U36.8 (~Q3)
unnamed: U26.14 (C4), U45.14 (I6)
unnamed: U26.9 (S1), U45.10 (I4)
unnamed: U26.6 (S2), U45.4 (I2)
unnamed: U26.2 (S3), U45.12 (I5)
unnamed: U26.15 (S4), U45.6 (I3)
unnamed: U27.12, U28.9 (Q1)
unnamed: U27.13, U28.8 (Q2)
unnamed: U27.10, U28.11 (Q3)
unnamed: U31.2 (D), U36.7 (D3), U42.8
unnamed: U31.6 (~Q), U37.1 (~R), U37.13 (~R), U41.4 (I2), U47.12 (D)
unnamed: U31.12 (D), U36.6 (D2), U42.10
unnamed: U32.2 (D0), U34.2 (D0), U35.7 (D3), U42.6
unnamed: U32.3 (D1), U34.3 (D1), U35.6 (D2), U42.4
unnamed: U32.6 (D2), U34.6 (D2), U35.3 (D1), U43.4
unnamed: U32.7 (D3), U34.7 (D3), U35.2 (D0), U43.10, U46.3, U46.4, U46.5
unnamed: U33.2 (D0), U36.3 (D1)
unnamed: U33.3 (D1), U36.2 (D0)
unnamed: U33.6 (D2), U43.8
unnamed: U33.7 (D3), U43.6
unnamed: U33.1 (~Q0), U38.1 (B), U38.10 (C), U44.12 (I5)
unnamed: U33.14 (~Q1), U44.14 (I6)
unnamed: U37.6 (~Q), U47.13 (~R)
unnamed: U13.13, U37.9 (Q)
unnamed: U38.4 (DOWN), U47.2 (D), U47.6 (~Q), U47.11 (C)
unnamed: U38.11 (~LOAD), U47.9 (Q)
unnamed: U41.12 (I5), U48.8 (~Q)
unnamed: U41.1 (OEa), U41.15 (OEb), U43.2, U48.11 (C)
unnamed: U46.6, U46.9
unnamed: U46.11, U46.12
unnamed: U46.8, U48.2 (D)
PHLDA: P1.26 (pHDLA), R4.2, U46.2
PINT: P1.73 (INT*), Q1.3 (C)
PRESET: P1.75 (RESET*), U23.10 (~S)
PSYNC: C1.1, P1.76 (pSYNC), U46.10

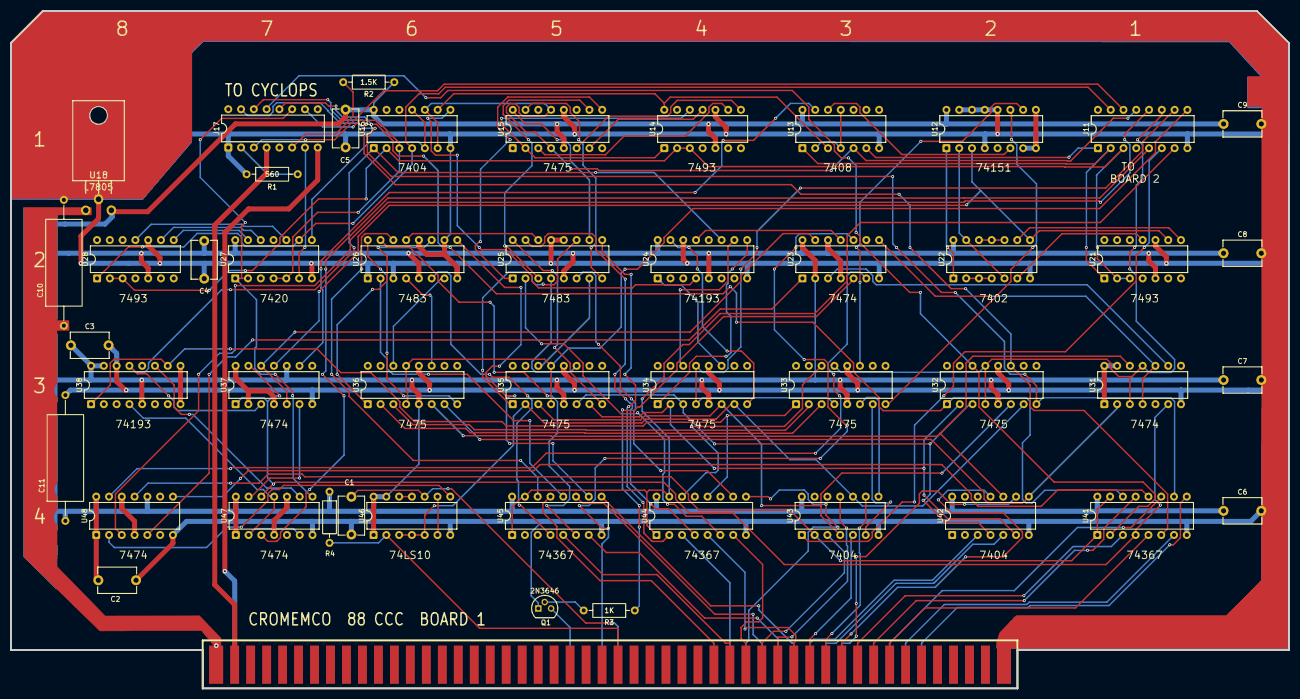
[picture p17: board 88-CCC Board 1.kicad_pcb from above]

Board: 2 copper layers, 254.0 x 134.6 mm, 49 parts (0 on the bottom side), 132 nets.

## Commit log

2025-12-06 Cleared PCB
    [88-CCC Board 1.kicad_pcb]
2025-12-08 Board 1 schematic updates
    [88-CCC Board 1.kicad_sch]
2025-12-08 Board 1 Schematics Update
    [88-CCC Board 1.kicad_sch]
2025-12-08 Schematic updates
    [88-CCC Board 1.kicad_sch, 88-CCC Board 2.kicad_pcb, 88-CCC Board 2.kicad_sch]
2025-12-10 Board 2 Schematics
    [88-CCC Board 2.kicad_sch]
2025-12-15 Board 2 schematic updates
    [88-CCC Board 2.kicad_sch]
2025-12-24 Board 1 PCB
    [88-CCC Board 1.kicad_pcb, 88-CCC Board 1.kicad_sch]
2026-03-30 Reproduction PCBs Final
    [88-CCC Board 1-B_Mask.gbs, 88-CCC Board 1-B_Paste.gbp, 88-CCC Board 1-B_Silkscreen.gbo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]
2026-04-21 Add image reference for 88 CCC reproduction boards
    Added image reference for 88 CCC reproduction boards.
2026-04-21 README
    Removed image reference for the 88 CCC reproduction boards.
